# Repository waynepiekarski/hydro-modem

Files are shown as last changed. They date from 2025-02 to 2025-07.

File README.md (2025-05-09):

# HydroModem: Underwater Bell 103 modem implementation for low-power microcontrollers

Main project page: https://waynepiekarski.net/projects/hydro-modem.htm

HydroModem is a Bell 103 modem implementation to decode data from an always-on underwater hydrophone.
Designed for low-power microcontrollers such as AVR ATmega328P, it can listen underwater long-term
and implement the reliable trigger for an acoustic release in ocean research sensor prototypes.

This is an implementation of a Bell 103 modem decoder for Arduino devices with
low-power microcontrollers such as ATmega328P. It uses a simple Goertzel algorithm
to detect the power of two frequencies, compares them to determine mark-space bits,
and then decodes these into 8-bit characters. This method can handle background noise
and is used here to implement an acoustic underwater data transmit/receive mechanism.
Low-power devices can be permanently placed underwater, listening for a wakeup message,
and then take some kind of action like burn a nichrome wire for an acoustic release.
It is expected that the modem will run on its own ATmega328P since there is no time remaining,
and a co-processor like another ATmega328P will listen to the decoded characters and take action.
HydroModem is an easy-to-use component that can be used for building low-cost devices to support
research in the world's oceans.

This implementation supports a 2600 Hz sample rate on an ATmega328P at 16 MHz. Transmission
is with sine wave tones at 1070 Hz and 1270 Hz. The sample rate must be at least double the highest frequency
(Nyquist theorem) and during testing at low signal strength some sample rates were found to be more reliable than
others due to aliasing. This implementation supports up to 3300 Hz, but beyond that requires a higher clock
rate on the microcontroller, possibly using something like an ESP32S3. The input is read
in via the Arduino ADC, which needs to be able to capture samples at the frequency required.

The ATmega328P must be run at 16 MHz for 2600 Hz sample rate, requires at least 4.0V for this clock speed according to the datasheet,
and will draw 7 mA current or 0.028 W power. This is 1-2 orders of magnitude better than a Raspberry Pi running Linux, and capable
of running for weeks/months on a battery underwater.

# Sample audio

Sample audio generated by the modem tests, with spectrogram of the FSK frequencies in use, click for video:<br>
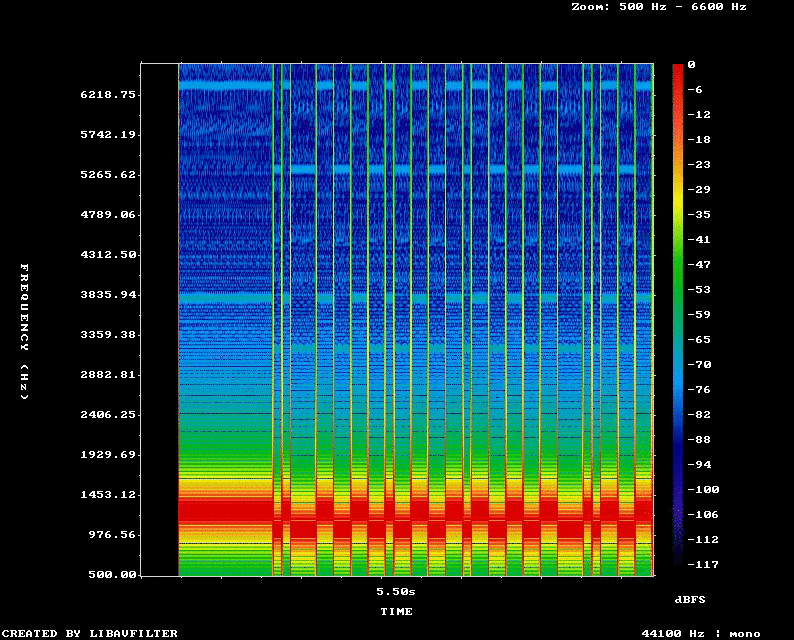
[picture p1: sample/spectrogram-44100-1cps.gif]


# Arduino Uno 16MHz on Linux command-line
The modemrx.ino project can be built on the command-line and also loaded into the Arduino IDE on any supported platform.
```
# Download arduino-cli (run once)
./download-arduino-tools

# Download arduino libraries (run once)
./download-arduino-libs

# Build and upload the modemrx project via USB serial
make -C modemrx upload

# Read characters decoded from the modemrx project
make -C modemrx read
```

# Listen and record audio on Linux via Arduino ADC
The recordwav.ino project allows you to listen to or record the audio at the ADC, making debugging with Linux tools easier.

```
# Download arduino-cli (run once)
./download-arduino-tools

# Download arduino libraries (run once)
./download-arduino-libs

# Build and upload the recordwav project via USB serial to record from the ADC
make -C recordwav upload

# Save audio to disk for offline testing
./recordwav/save_arduino_piezo.sh

# Listen to live audio on speakers
./recordwav/live_arduino_piezo.sh
```

# Linux testing of modem

The modem code also builds on Linux with the ability to encode to and decode from WAV files.
Automated regression tests are provided to ensure that different sample rates all work after changes are made.
Tests also verify that HydroModem's Bell 103 encoding is compatible with MiniModem <a href="http://www.whence.com/minimodem/">http://www.whence.com/minimodem/</a> on Linux.

```
# Download Debian/Ubuntu dependencies (run once)
./linux-test/apt-get-deps

# Build Linux binaries
make -C linux-test

# Generate WAV files using test strings
./linux-test/bell103_goertzel_wav_encoder

# Decode WAV files and recover test strings
./linux-test/bell103_goertzel_wav_decoder

# Run test suite that verifies encoding and decoding at various sample rates.
make -C linux-test test
```

# KiCAD v5 schematics and PCB layouts

These designs need to be tested in water and frequencies tuned for best performance.
Full project files are provided, including .kicad_pcb files for fabrication at <a href="https://oshpark.com">oshpark.com</a>.

## kicad/release-modem-mosfet-atmega328p-piezo/

Combination design implementing both the modem and the release mechanism.
5V ATmega328P running at 16 MHz.
Connects to a piezo-based microphone and includes protection diodes and an OPA1641 op-amp based on the
<a href="https://www.instructables.com/The-Gladys-Hydrophone/">Gladys Hydrophone by DJJules</a>.
Implements a P-channel MOSFET that can switch high-current 30 amps briefly to burn a nichrome release wire under water.
Provides on-board MCP1792 regulator for 5V from a >= 6.2V battery.
Arduino Uno-compatible AVRISP6 connector for programming.

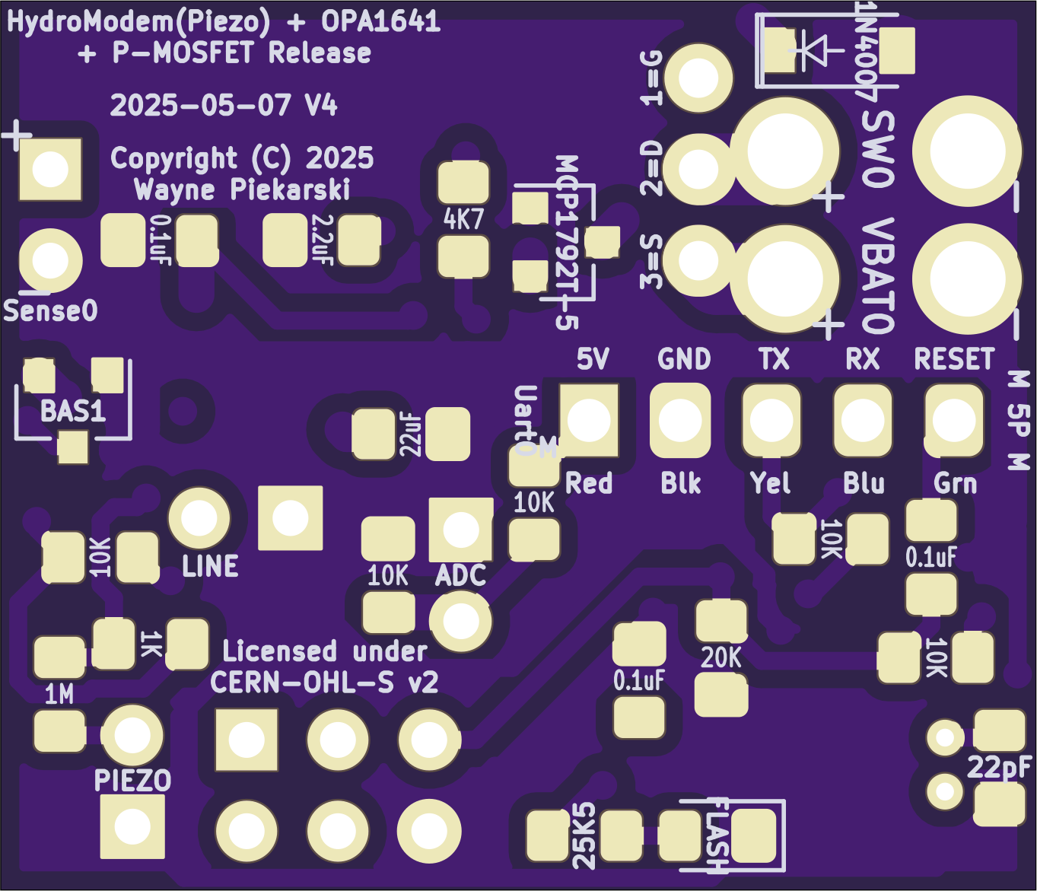
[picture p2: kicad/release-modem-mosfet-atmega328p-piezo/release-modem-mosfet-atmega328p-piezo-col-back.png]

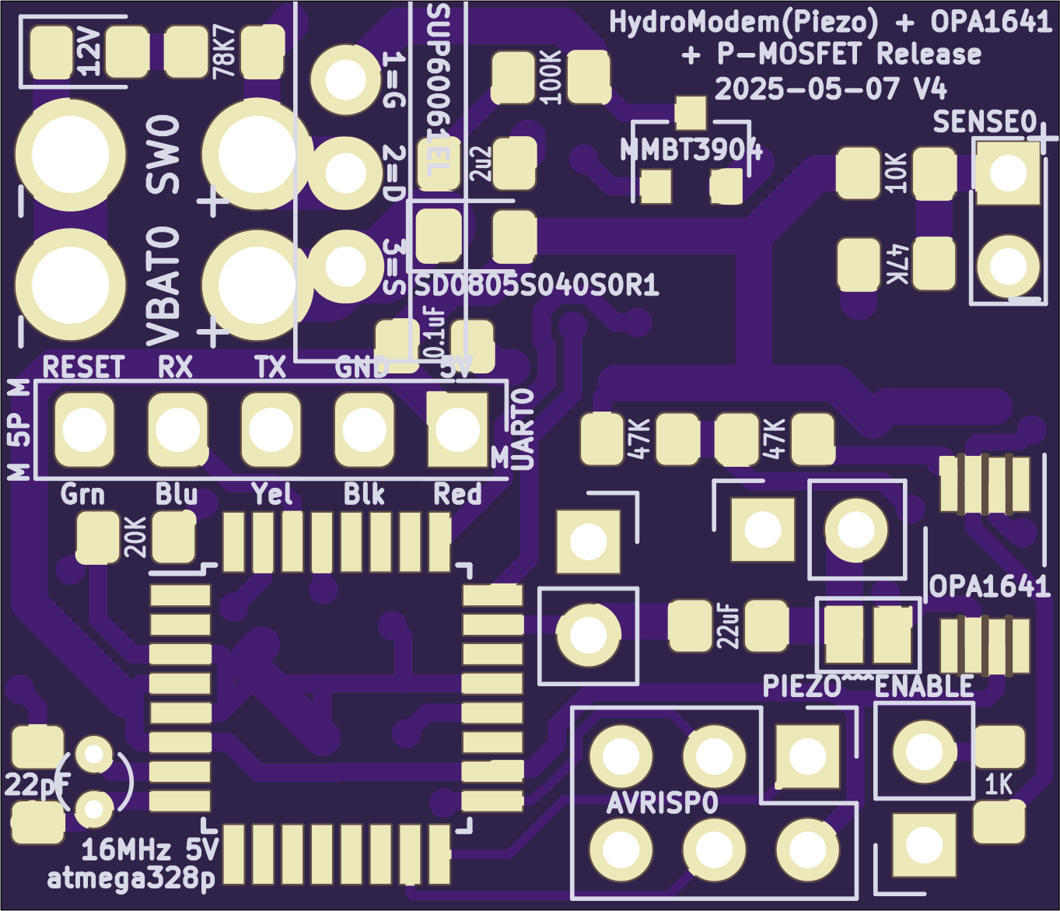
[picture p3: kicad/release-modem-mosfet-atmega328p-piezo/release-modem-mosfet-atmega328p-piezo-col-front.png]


<a href="kicad/release-modem-mosfet-atmega328p-piezo/release-modem-mosfet-atmega328p-piezo-schematic.pdf?raw=1">Schematics PDF</a>

<a href="kicad/release-modem-mosfet-atmega328p-piezo/design.kicad_pcb?raw=1">kicad_pcb</a>

## kicad/release-modem-atmega328p/

5V ATmega328P running at 16 MHz. Requires regulated 5V provided by the other board.
Connects to a piezo-based microphone and includes protection diodes and an OPA1641 op-amp based on the
<a href="https://www.instructables.com/The-Gladys-Hydrophone/">Gladys Hydrophone by DJJules</a>.
Only runs the HydroModem implementation, was used for early testing and separate from the release mechanism.
Arduino Uno-compatible AVRISP6 connector for programming.

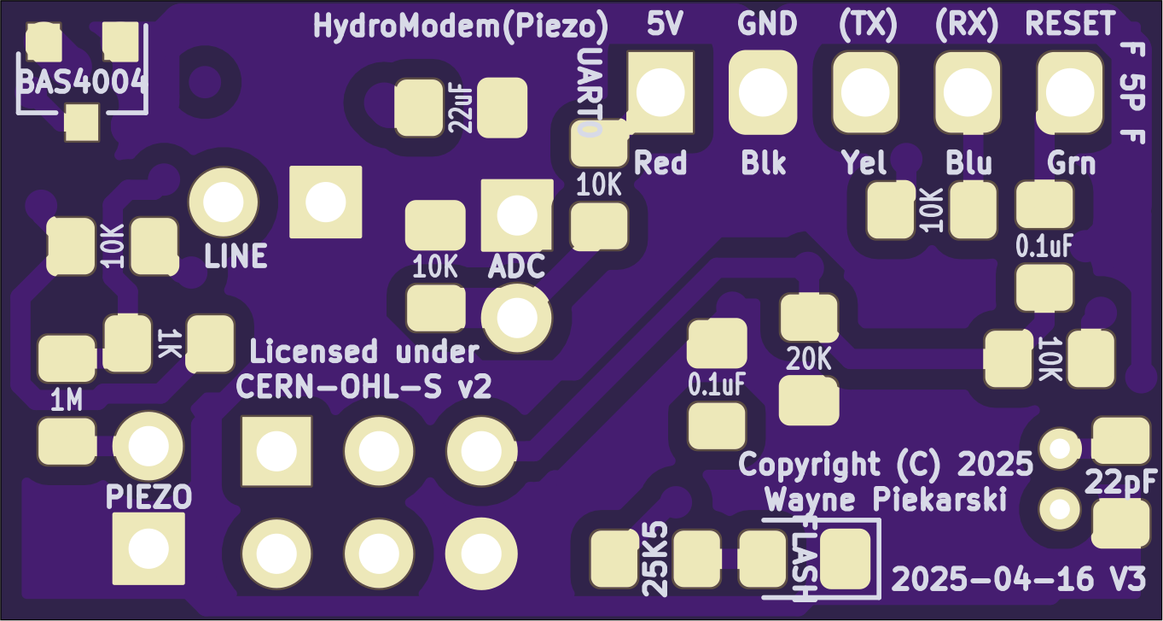
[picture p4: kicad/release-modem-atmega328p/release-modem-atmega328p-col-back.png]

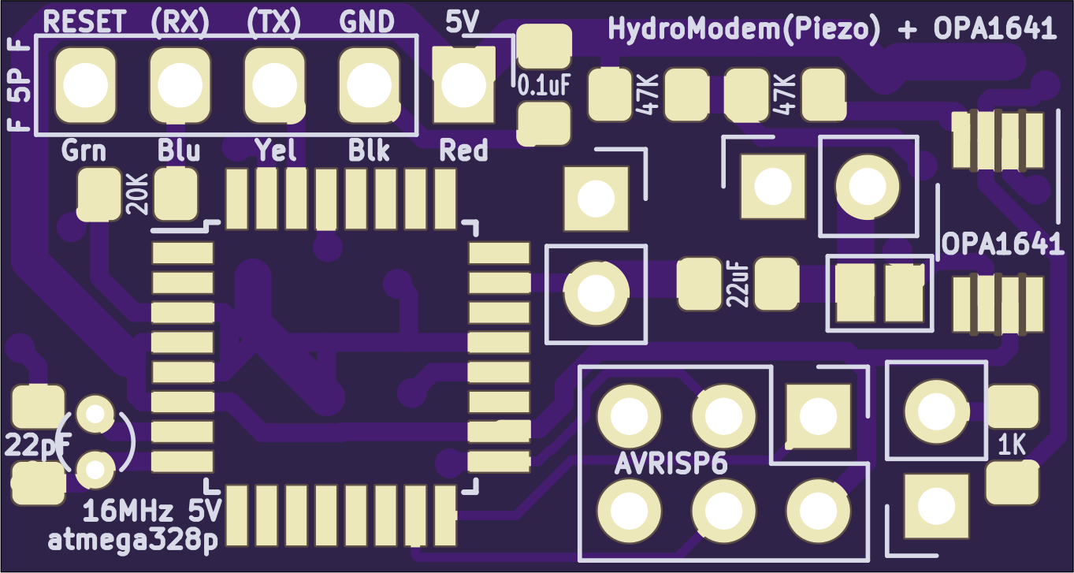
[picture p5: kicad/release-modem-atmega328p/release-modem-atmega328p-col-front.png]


<a href="kicad/release-modem-atmega328p/release-modem-atmega328p-schematic.pdf?raw=1">Schematics PDF</a>

<a href="kicad/release-modem-atmega328p/design.kicad_pcb?raw=1">kicad_pcb</a>

## kicad/release-modem-atmega328p-linein/

This is a simplified PCB design that does not provide any amplification for a piezo.
It connects any microphone that has been amplified to line-in voltages (+/- 1V) and passes this through to the ADC.
Only runs the HydroModem implementation and no release mechanism.

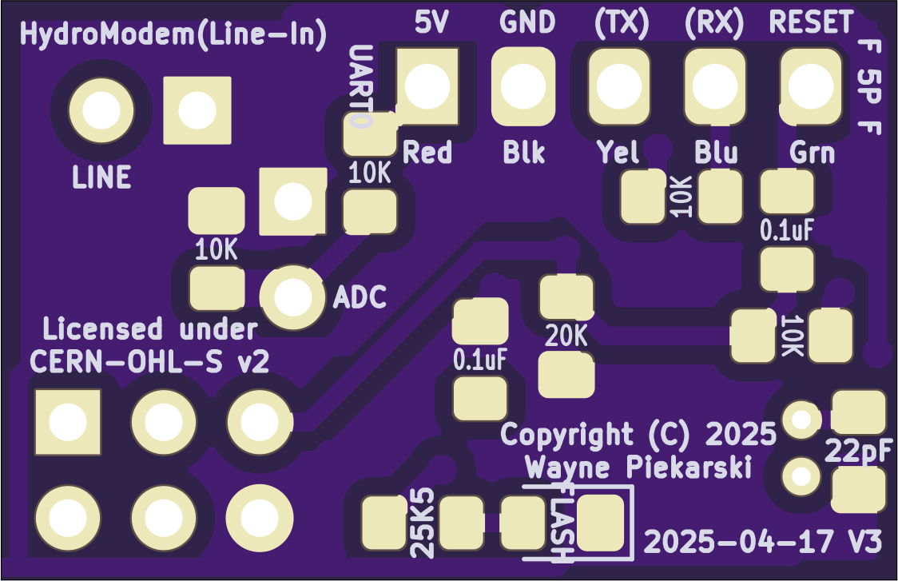
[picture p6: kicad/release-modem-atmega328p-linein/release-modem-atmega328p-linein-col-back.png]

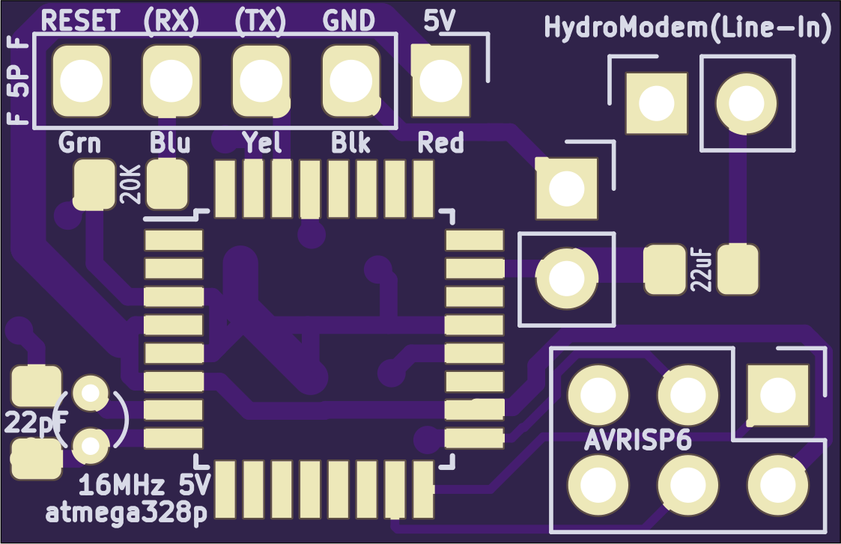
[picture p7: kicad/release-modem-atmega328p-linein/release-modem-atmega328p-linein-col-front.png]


<a href="kicad/release-modem-atmega328p-linein/release-modem-atmega328p-linein-schematic.pdf?raw=1">Schematics PDF</a>

<a href="kicad/release-modem-atmega328p-linein/design.kicad_pcb?raw=1">kicad_pcb</a>

## kicad/release-serial-i2c-atmega328p-switch/

3.3V ATmega328P running at 8 MHz. Implements a MOSFET that can switch high-current to burn a nichrome release wire.
Provides on-board MCP1792 regulators for 3.3V and 5V from a >= 6.2V battery. Arduino Uno-compatible AVRISP6 connector
for programming. Works with either of the standalone modem implementations above.

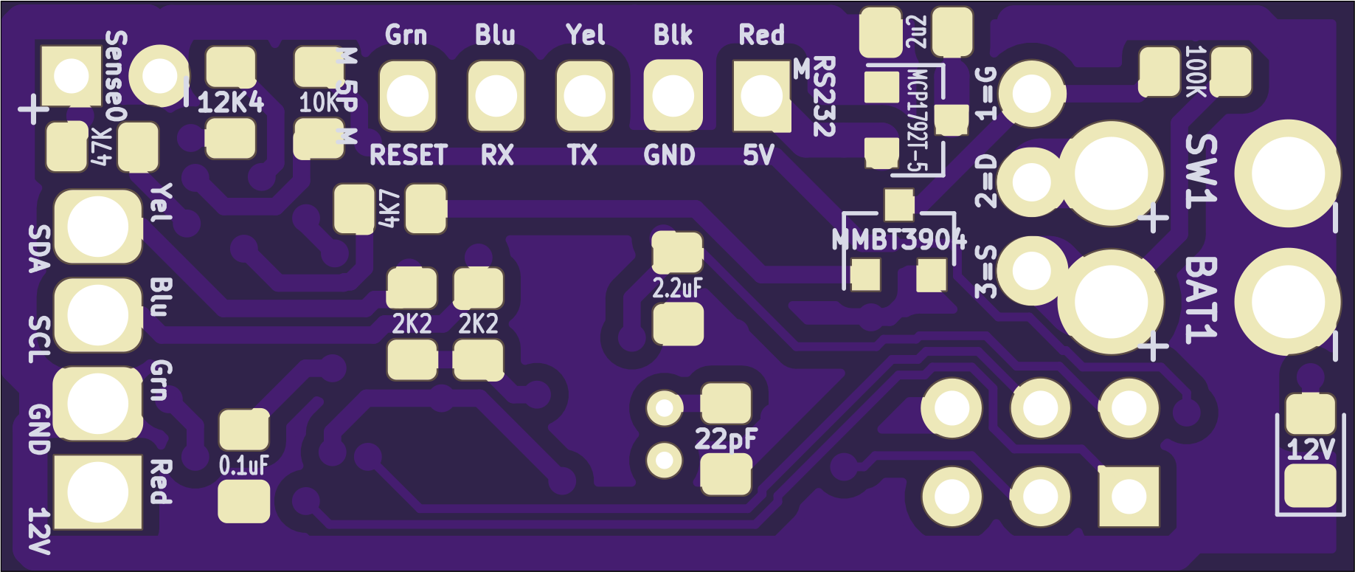
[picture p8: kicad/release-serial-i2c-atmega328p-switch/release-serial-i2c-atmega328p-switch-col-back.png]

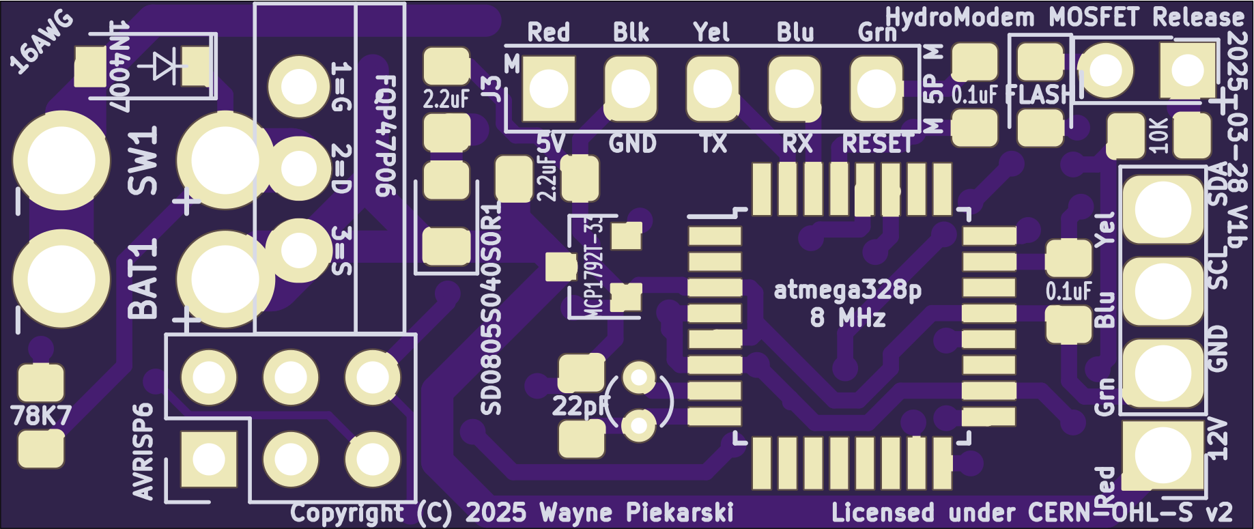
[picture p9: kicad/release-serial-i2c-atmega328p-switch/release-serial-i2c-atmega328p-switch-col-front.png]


<a href="kicad/release-serial-i2c-atmega328p-switch/release-serial-i2c-atmega328p-switch-schematic.pdf?raw=1">Schematics PDF</a>

<a href="kicad/release-serial-i2c-atmega328p-switch/design.kicad_pcb?raw=1">kicad_pcb</a>

# Source code GPLv3 license

HydroModem: Underwater Bell 103 modem implementation for low-power microcontrollers

Copyright (C) 2024-2025 Wayne Piekarski wayne@tinmith.net

https://waynepiekarski.net/projects/hydro-modem.htm

This program is free software: you can redistribute it and/or modify
it under the terms of the GNU General Public License as published by
the Free Software Foundation, either version 3 of the License, or
(at your option) any later version.

This program is distributed in the hope that it will be useful,
but WITHOUT ANY WARRANTY; without even the implied warranty of
MERCHANTABILITY or FITNESS FOR A PARTICULAR PURPOSE.  See the
GNU General Public License for more details.

You should have received a copy of the GNU General Public License
along with this program.  If not, see <http://www.gnu.org/licenses/>.

# KiCAD Schematics and PCB license CERN-OHL-S v2

This source describes Open Hardware and is licensed under the CERN-OHL-S v2.

You may redistribute and modify this source and make products using it under
the terms of the CERN-OHL-S v2 (https://ohwr.org/cern_ohl_s_v2.txt).

This source is distributed WITHOUT ANY EXPRESS OR IMPLIED WARRANTY,
INCLUDING OF MERCHANTABILITY, SATISFACTORY QUALITY AND FITNESS FOR A
PARTICULAR PURPOSE. Please see the CERN-OHL-S v2 for applicable conditions.

Source location: https://www.waynepiekarski.net/projects/hydro-modem.htm

As per CERN-OHL-S v2 section 4, should You produce hardware based on this
source, You must where practicable maintain the Source Location visible
on the external case of the device or other products you make using this
source.

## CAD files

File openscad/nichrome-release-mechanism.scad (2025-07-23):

// ------------------------------------------------------------------------------
//| HydroModem - Nichrome Release Mechanism                                      |
//| Copyright (C) Wayne Piekarski 2024-2025                                      |
//| https://www.waynepiekarski.net/projects/hydro-modem.htm                      |
//|                                                                              |
//| This source describes Open Hardware and is licensed under the CERN-OHL-S v2. |
//|                                                                              |
//| You may redistribute and modify this source and make products using it under |
//| the terms of the CERN-OHL-S v2 (https://ohwr.org/cern_ohl_s_v2.txt).         |
//|                                                                              |
//| This source is distributed WITHOUT ANY EXPRESS OR IMPLIED WARRANTY,          |
//| INCLUDING OF MERCHANTABILITY, SATISFACTORY QUALITY AND FITNESS FOR A         |
//| PARTICULAR PURPOSE. Please see the CERN-OHL-S v2 for applicable conditions.  |
//|                                                                              |
//| Source location: https://www.waynepiekarski.net/projects/hydro-modem.htm     |
//|                                                                              |
//| As per CERN-OHL-S v2 section 4, should You produce hardware based on this    |
//| source, You must where practicable maintain the Source Location visible      |
//| on the external case of the device or other products you make using this     |
//| source.                                                                      |
// ------------------------------------------------------------------------------

// Nichrome 80 wire, 32 AWG
// https://www.amazon.com/dp/B07CJ63YYT
// Nichrome 80-250' - 32 Gauge Wire - 250ft - 0.2mm - 0.008in - Made in USA - Master Wire Supply

mount_width = 10; // Using 10mm square washers with M3 holes to grab onto the nichrome wire
wire_length = 10; // Gap between washers for the nichrome wire to burn
bolt_length = 20;

base = 5;
height = 20;
length = 100;
width = mount_width*2 + wire_length;

arm_height = height - 5;
arm_offset = 1; // Need clearance or the arm is a tight fit to close
bolt_height = arm_height / 2;
arm_thickness = wire_length-2;

infinity = 100;

for (copy=[-1,1]) scale([copy,1,1]) {
    // Base with text
    if (copy > 0) {
        difference() {
            translate([0,0,-base/2])
                cube([width,length,base], center=true);
            translate([0,0,-1]) linear_extrude(2) {
                translate([-6,-2,0])
                    rotate([0,0,90])
                        text("Nichrome 80 32AWG", halign="center", valign="bottom", size=5);
                translate([0,+2,0])
                    rotate([0,0,90])
                        text("2025-06-11 v1", halign="center", valign="center", size=5);
                translate([+6,+2,0])
                    rotate([0,0,90])
                        text("HydroModem", halign="center", valign="top", size=5);
            }
        }
    }

    // Mount for rotating release arm bolt
    translate([width/2-mount_width,-length/2,0]) {
        difference() {
            cube([mount_width,2*arm_thickness,height]);
            translate([0,arm_thickness,bolt_height+arm_offset])
                rotate([0,90,0])
                    cylinder(d=6, $fn=4, h=infinity, center=true);
        }
    }

    // Mount for the electrical metric bolts
    translate([-mount_width/2+mount_width/2+wire_length/2,length/2-bolt_length,0]) {
        difference() {
            union() {
                inset = 3;
                // Inset slightly so the square washers do not rotate
                translate([0,inset,mount_width])
                    color("green") cube([mount_width,bolt_length-2*inset,mount_width]);
                color("orange") cube([mount_width,bolt_length,height-mount_width]);
            }
            translate([mount_width/2,0,height-mount_width/2+arm_offset])
                rotate([90,0,0])
                    cylinder(d=3, $fn=4, h=infinity, center=true);
        }
    }
}

// The hole didn't line up and needs an 0.5mm offset to align properly.
// Use *0 or *1 there are two places where it can be enabled.
bugfix = 0.5;

// Rotating rope holding arm with rounded ends
debug = false;
color("orange")
translate(debug ? [0,bugfix*1,arm_height/2+arm_offset] : [width,0,arm_thickness/2-base]) rotate(debug ? [0,0,0] : [0,90,0])
{
    difference() {
        hull() {
            translate([0,length/2-arm_height/2,0])
                rotate([0,90,0])
                    cylinder(d=arm_height, $fn=100, h=arm_thickness, center=true);
            translate([0,-(length/2-arm_height/2),0])
                rotate([0,90,0])
                    cylinder(d=arm_height, $fn=100, h=arm_thickness, center=true);
        }
        // Bolt hole for rotation
        translate([0,-(length/2-arm_height/2-bugfix*0),0])
            rotate([0,90,0])
                cylinder(d=6, $fn=100, h=infinity, center=true);
        
        // Area for rope to pass through, needs to be at an angle
        // so the rope slides out and doesn't get caught
        tweak_angle = 15;
        tweak_ofs = 2.8;
        rope_diameter = 10;

        translate([0,-length/2+arm_height*1.5,0-arm_height/2-tweak_ofs])
            rotate([0,90,0])
                rotate([0,0,tweak_angle])
                cylinder(d=rope_diameter*2, $fn=4, h=infinity, center=true);
    }
}

// Rotating rope holding arm with bolt end to not burn from nichrome
// TODO: Currently will be at an angle since the nichrome wire is higher than axis of rotation
debug2 = false;
color("cyan")
translate(debug2 ? [0,bugfix*1,arm_height/2+arm_offset] : [-width,0,arm_thickness/2-base]) rotate(debug2 ? [0,0,0] : [0,90,0])
{
    difference() {
        hull() {
            // -5mm to ensure the arm never interferes with the nichrome mount
            translate([0,length/2-arm_height/2-bolt_length-5,0])
                rotate([0,90,0])
                    cube([arm_height,arm_height,arm_thickness], center=true);
            translate([0,-(length/2-arm_height/2),0])
                rotate([0,90,0])
                    cylinder(d=arm_height, $fn=100, h=arm_thickness, center=true);
        }
        // Mounting hole to fasten M3 bolt to rest against the nichrome wire
        rotate([90,0,0])
            translate([0,0,-infinity/2])
                cylinder(d=3, $fn=4, h=infinity, center=true);
        
        // Bolt hole for rotation
        translate([0,-(length/2-arm_height/2-bugfix*0),0])
            rotate([0,90,0])
                cylinder(d=6, $fn=100, h=infinity, center=true);
        
        // Area for rope to pass through, needs to be at an angle
        // so the rope slides out and doesn't get caught
        tweak_angle = 15;
        tweak_ofs = 2.8;
        rope_diameter = 10;

        translate([0,-length/2+arm_height*1.5,0-arm_height/2-tweak_ofs])
            rotate([0,90,0])
                rotate([0,0,tweak_angle])
                cylinder(d=rope_diameter*2, $fn=4, h=infinity, center=true);
    }
}

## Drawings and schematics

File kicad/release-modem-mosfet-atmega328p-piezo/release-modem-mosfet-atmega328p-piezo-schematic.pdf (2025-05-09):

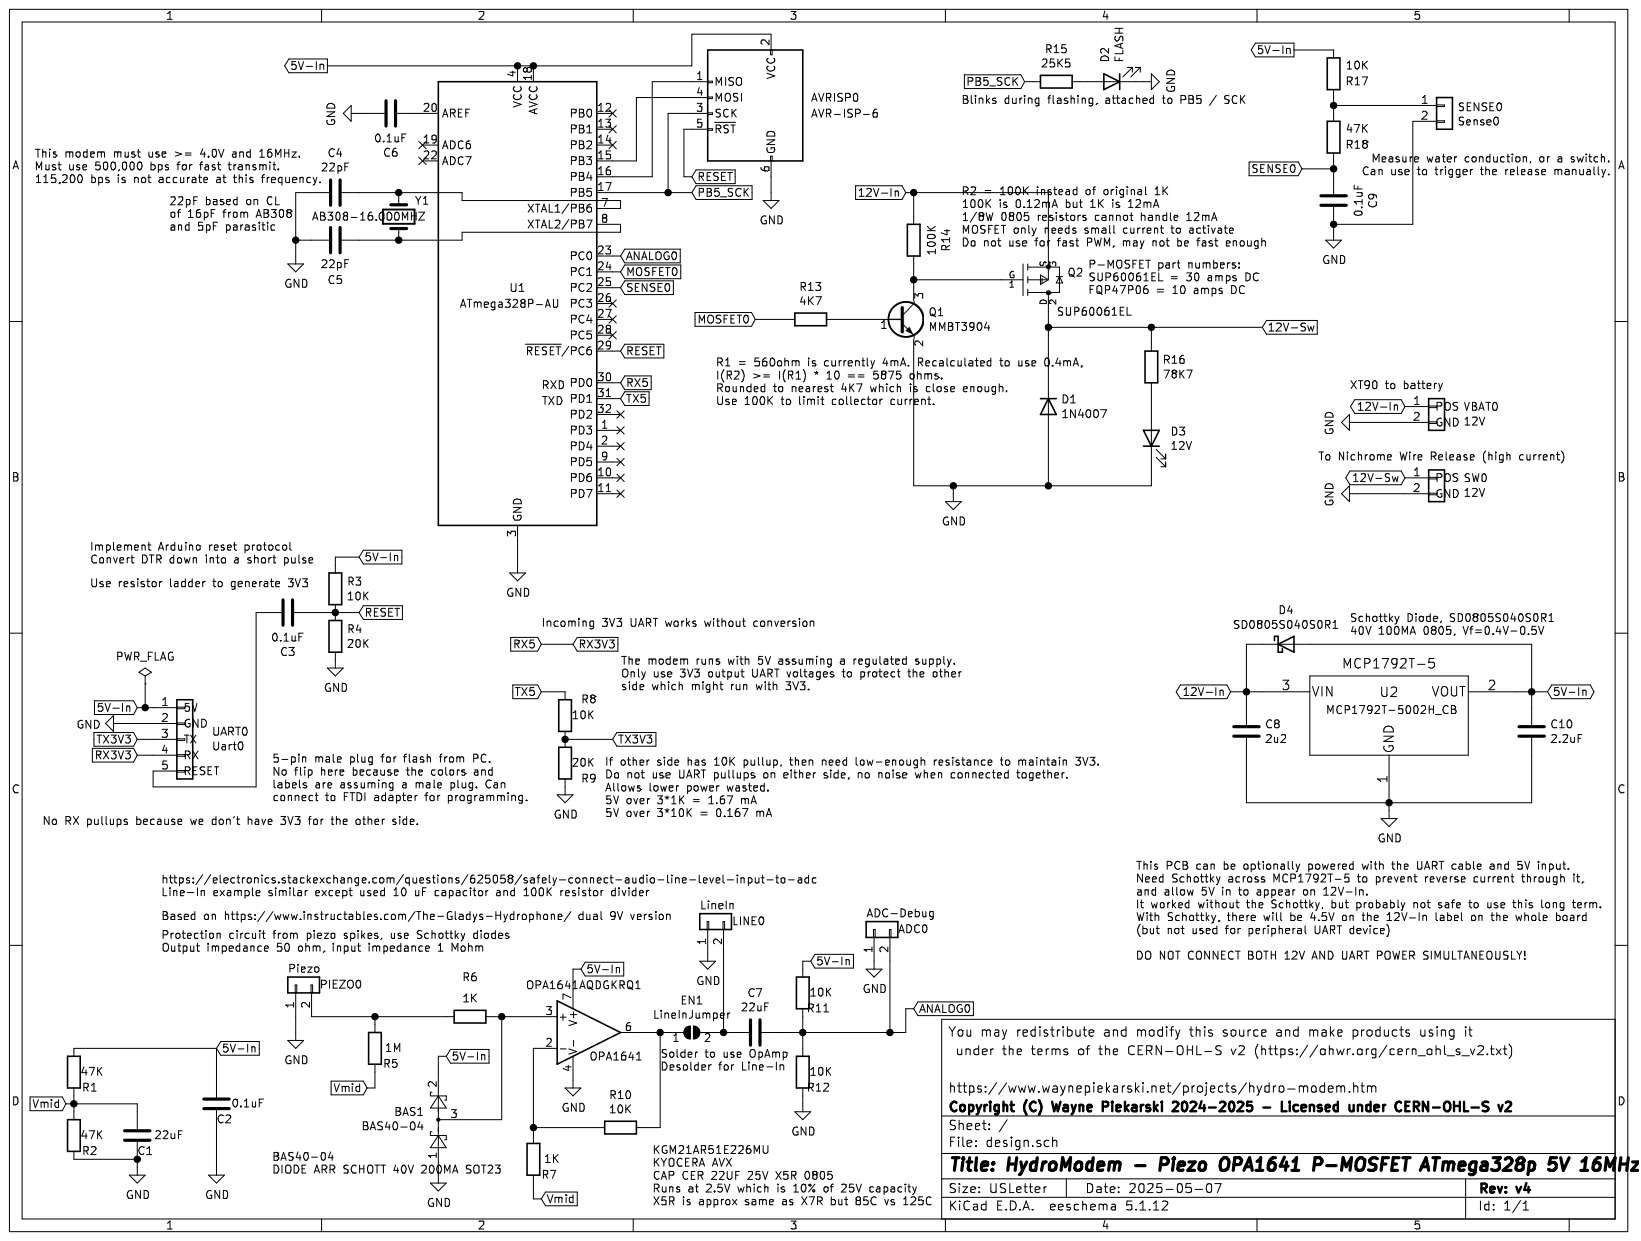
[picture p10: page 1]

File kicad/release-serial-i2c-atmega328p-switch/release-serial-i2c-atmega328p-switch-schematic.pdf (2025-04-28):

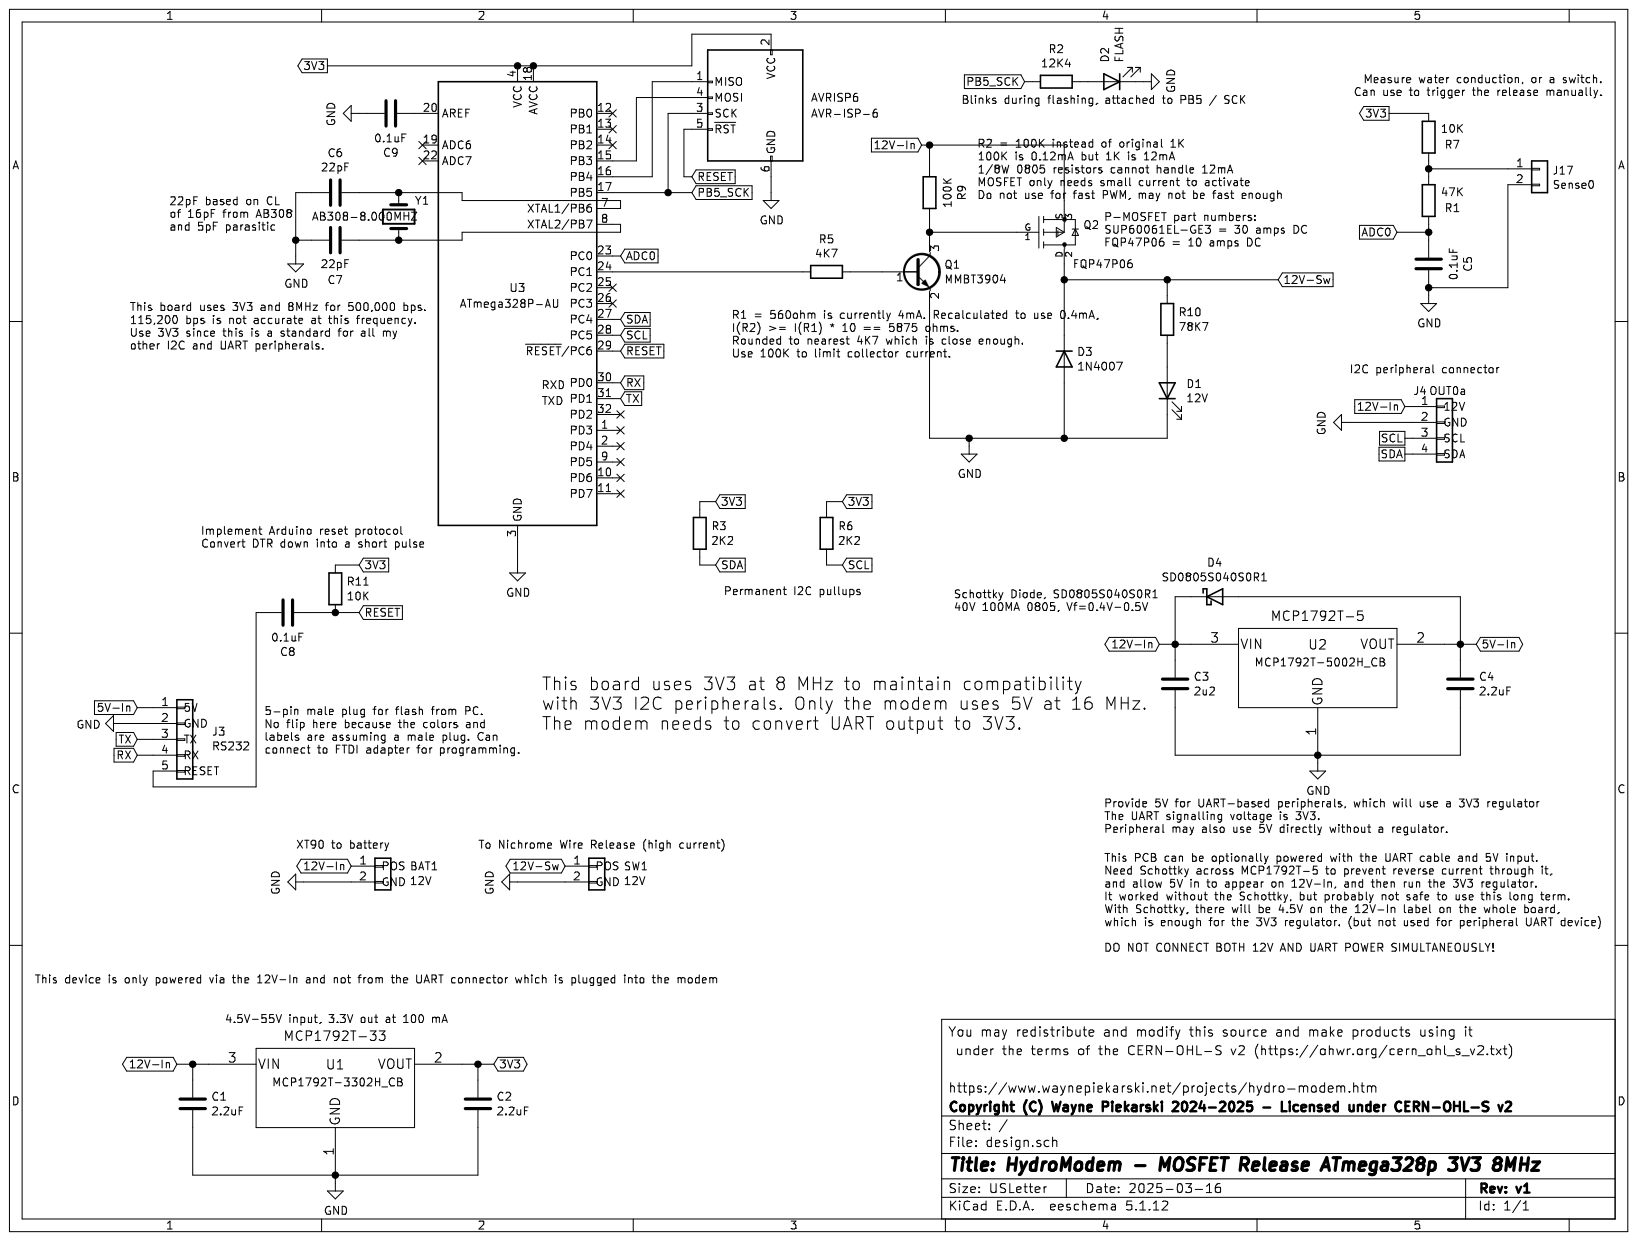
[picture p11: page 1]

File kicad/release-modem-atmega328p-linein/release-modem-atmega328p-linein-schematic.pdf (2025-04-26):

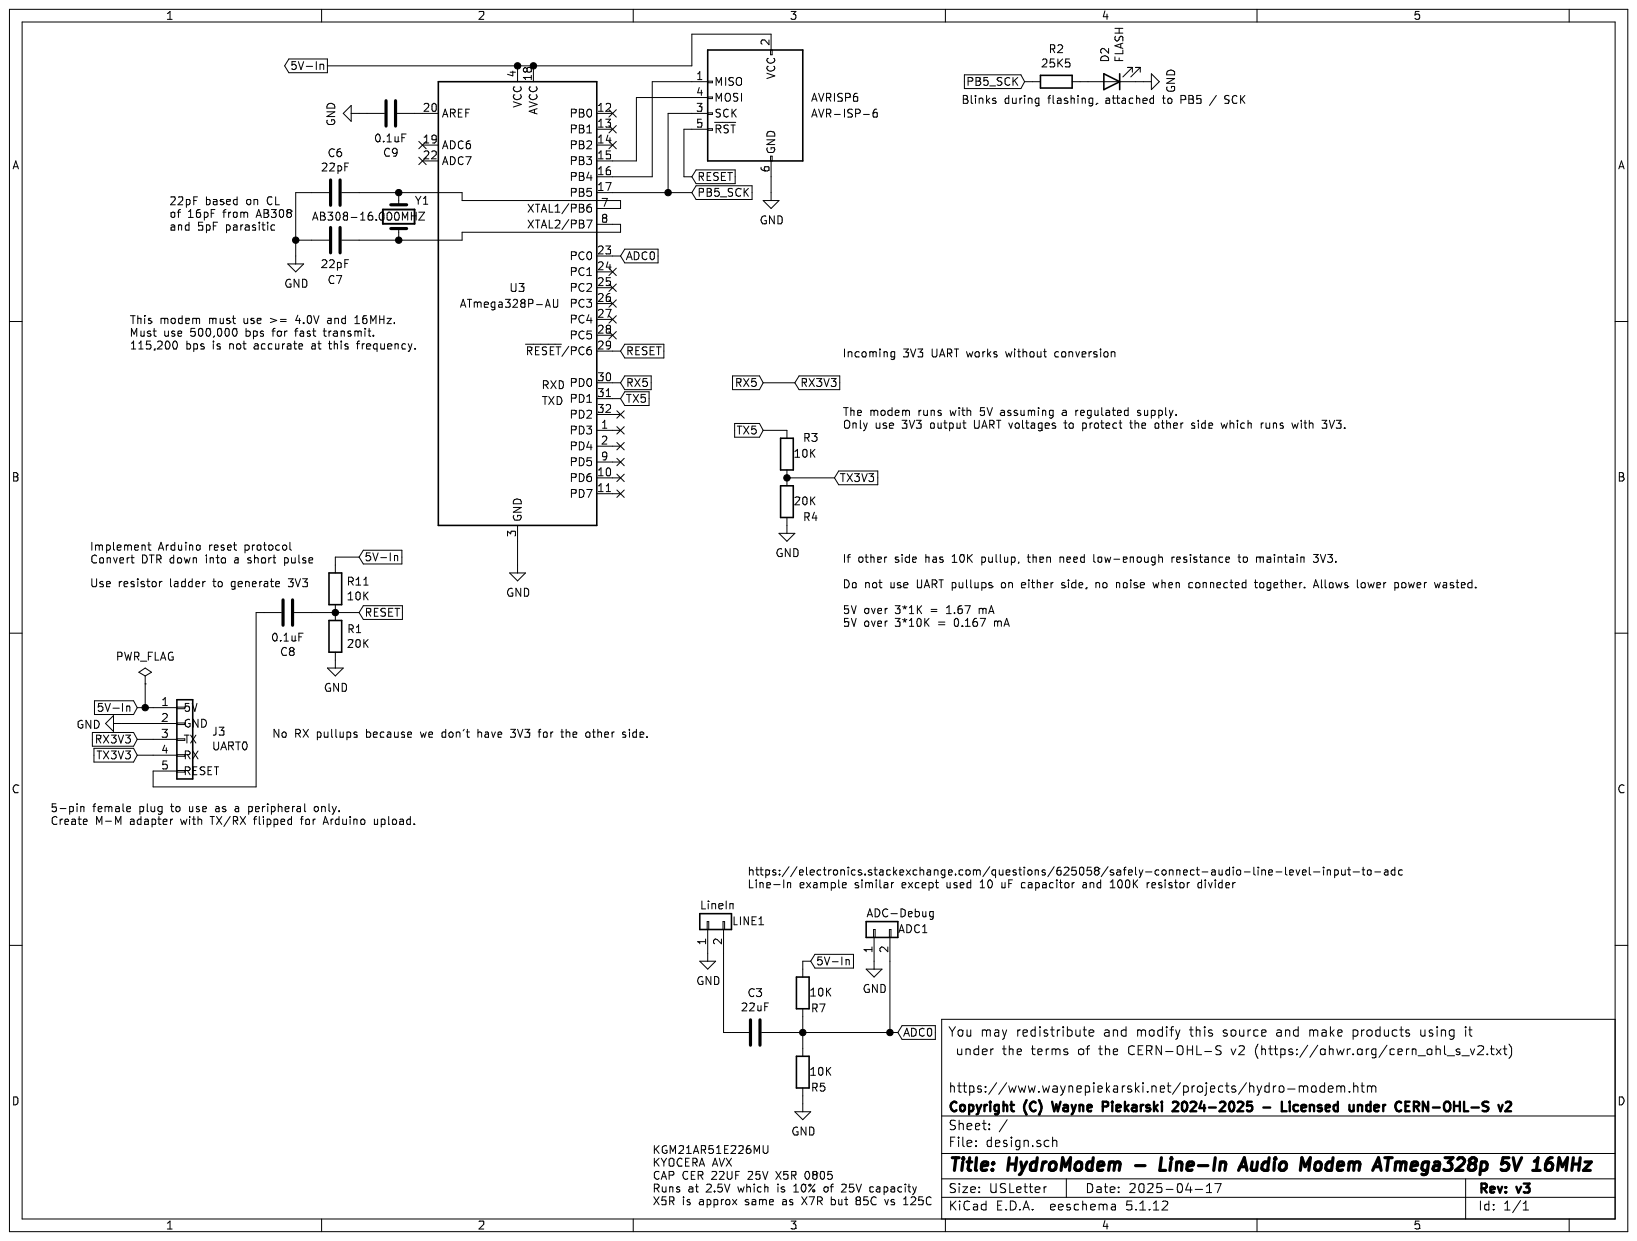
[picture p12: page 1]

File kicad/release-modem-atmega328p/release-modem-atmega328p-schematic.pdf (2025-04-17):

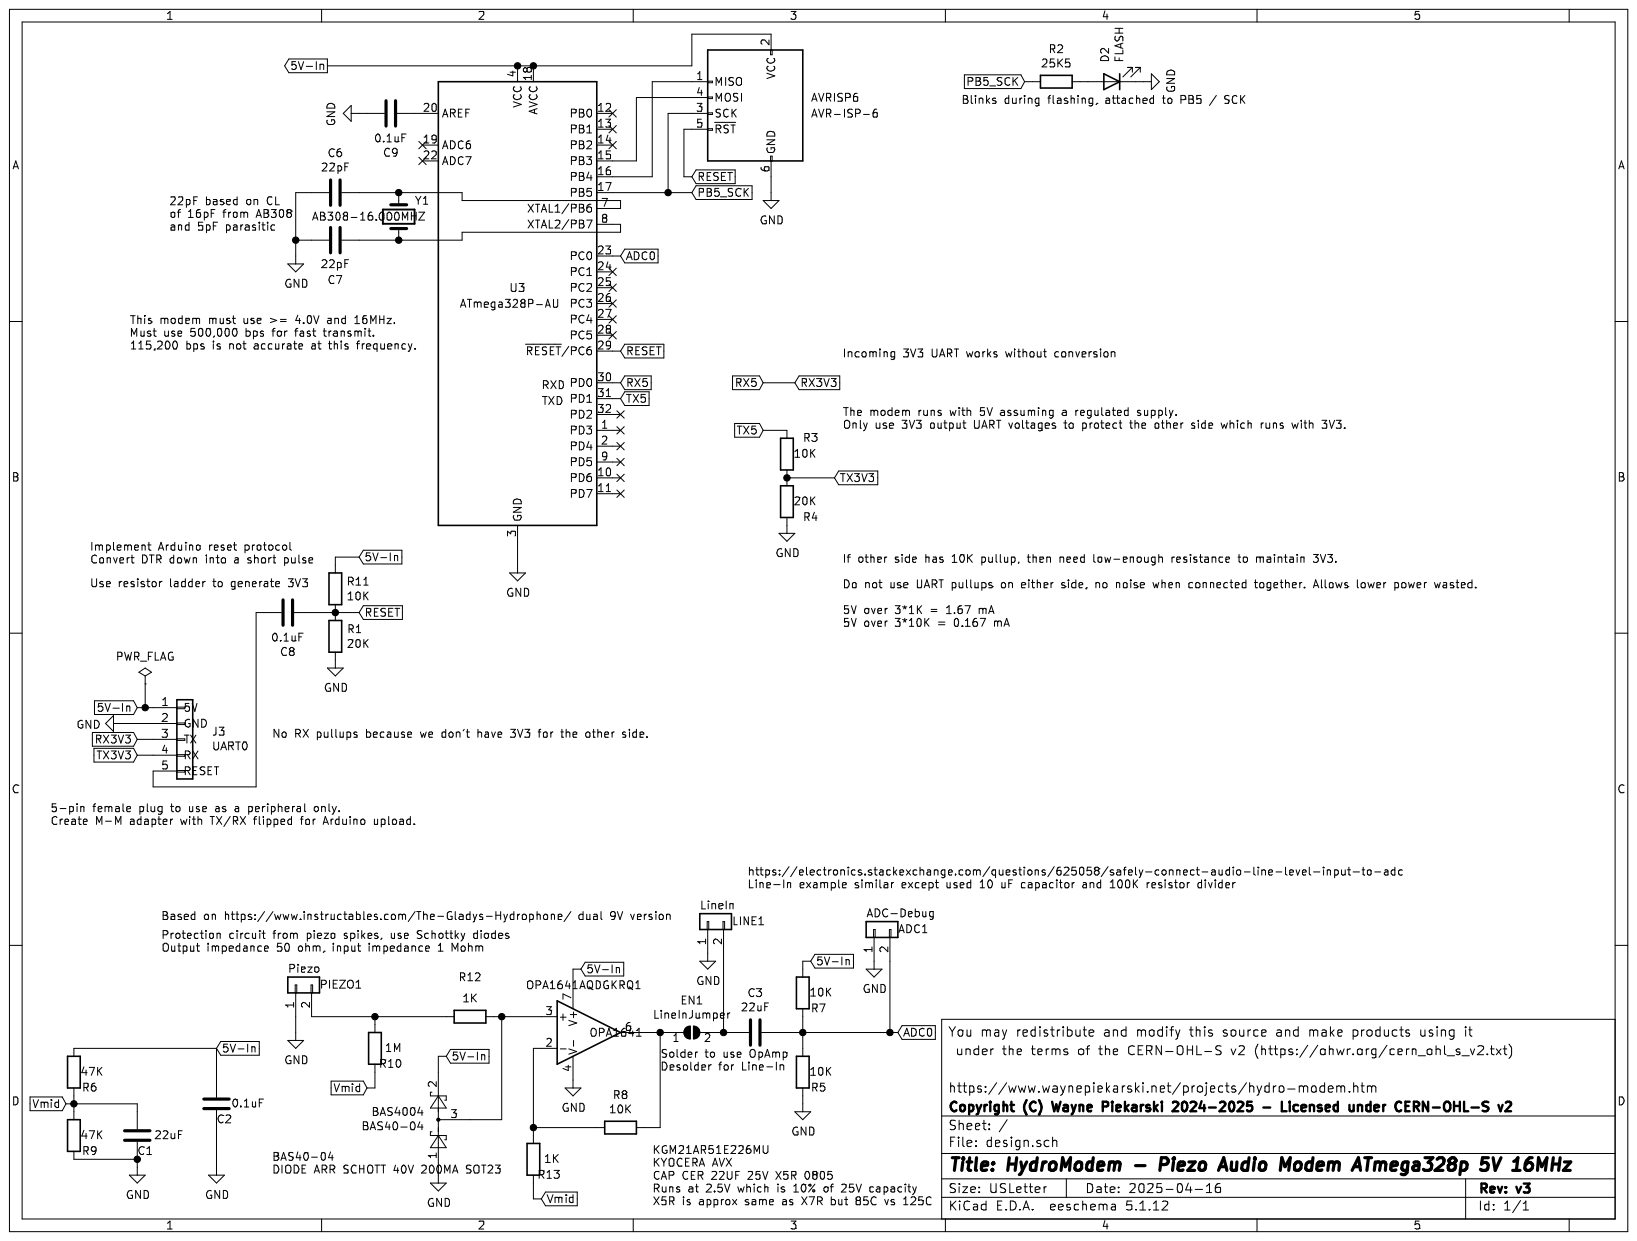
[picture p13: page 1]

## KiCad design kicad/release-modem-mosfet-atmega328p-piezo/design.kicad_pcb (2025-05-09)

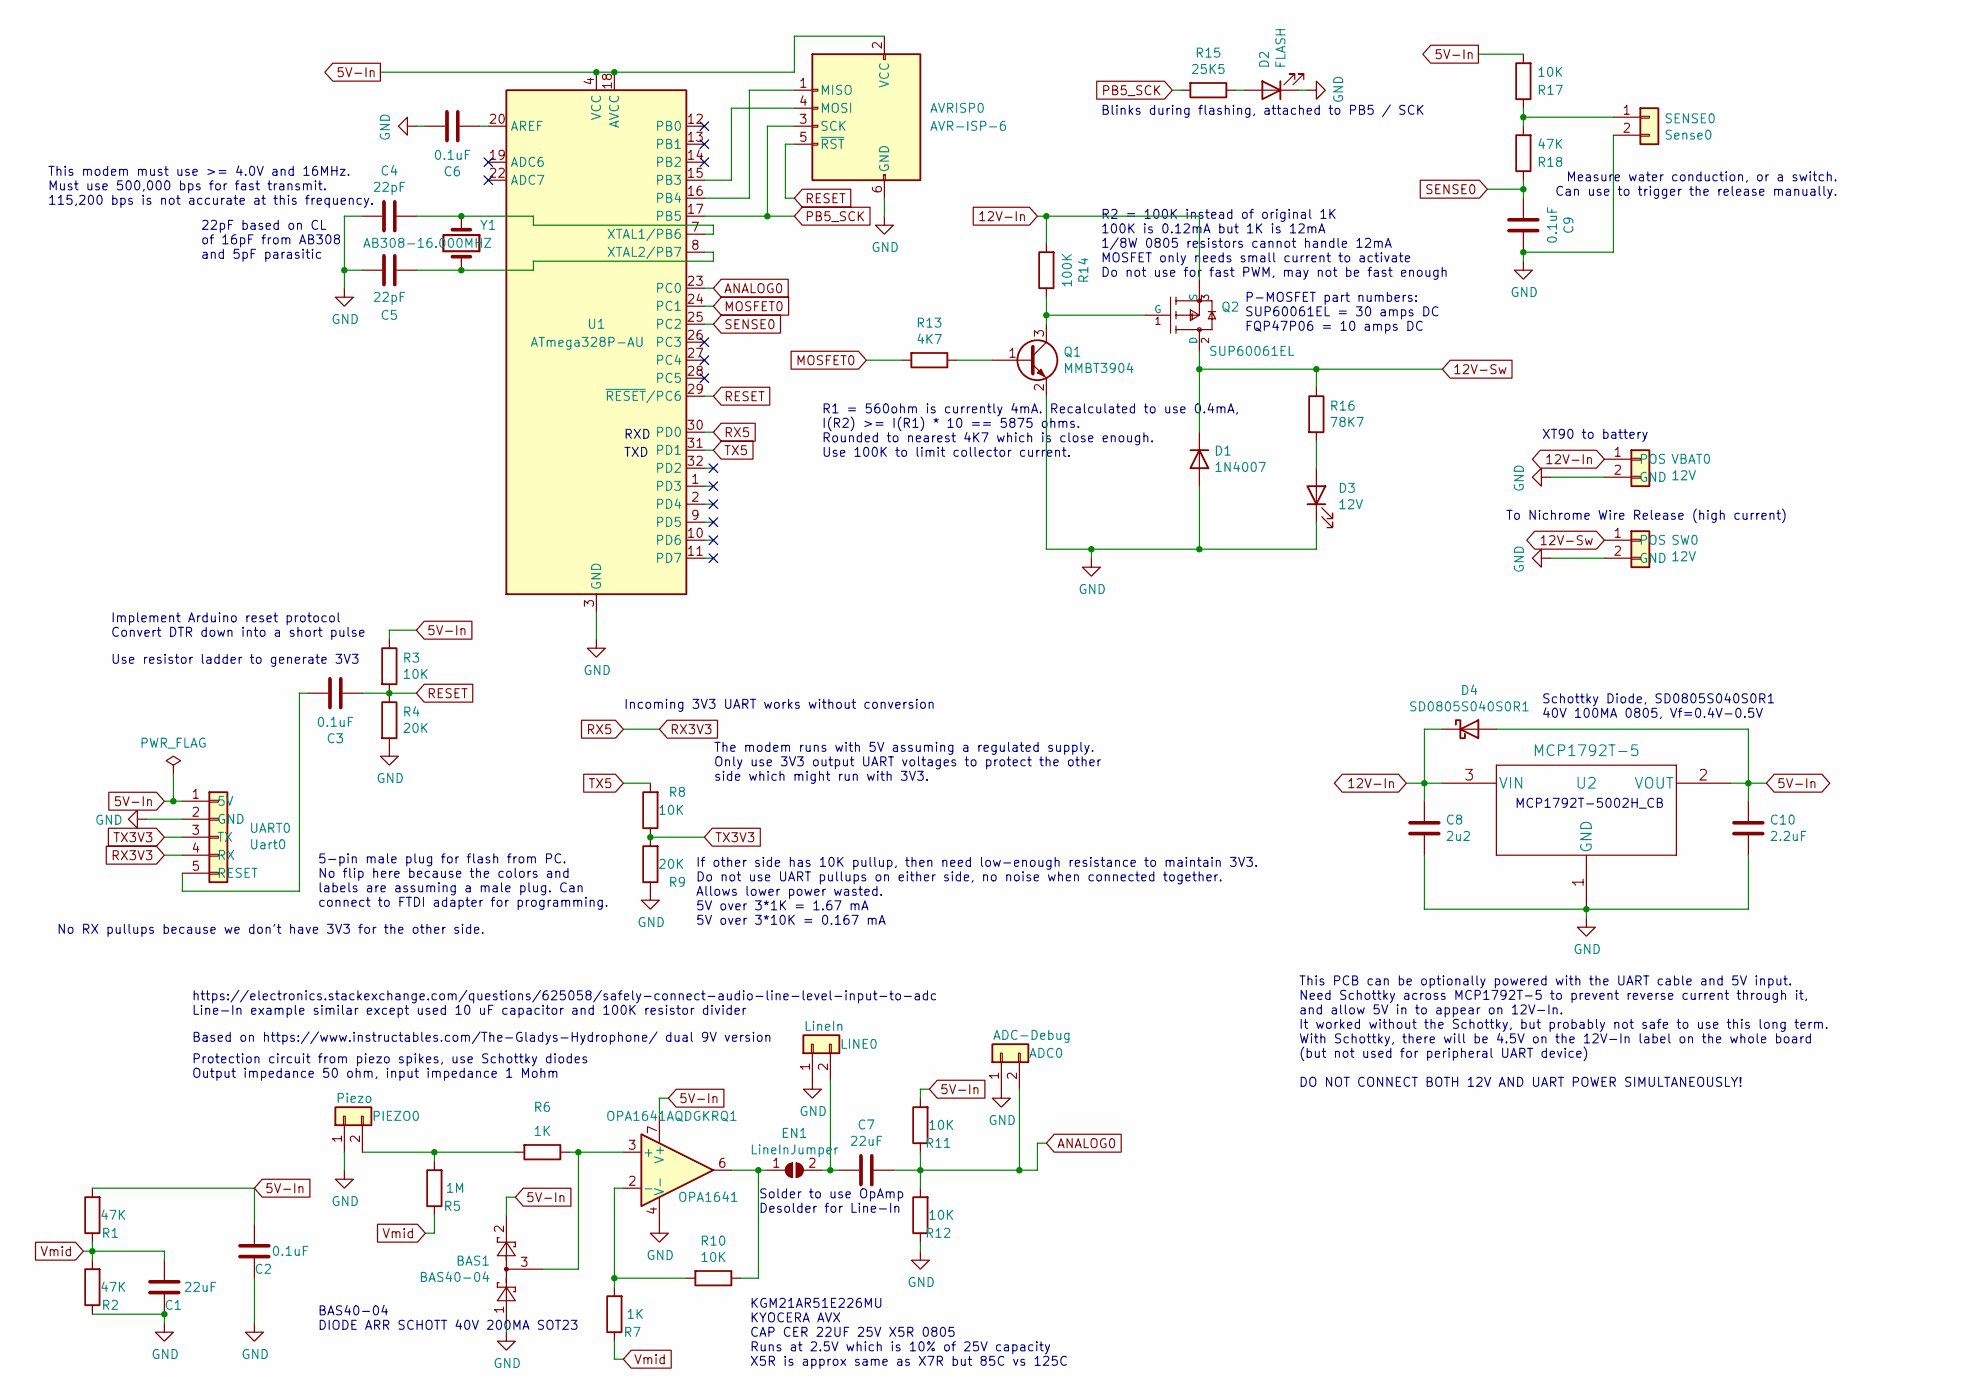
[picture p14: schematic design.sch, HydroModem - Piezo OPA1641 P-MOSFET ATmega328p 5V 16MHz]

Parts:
ADC0: ADC-Debug; WP_PinSocket_1x02_P2.54mm_Vertical
AVRISP0: AVR-ISP-6; PinHeader_2x03_P2.54mm_Vertical
BAS1: BAS40-04; SOT-23
C1, C7: 22uF; WP_C_0805_2012Metric_Pad1.15x1.40mm_HandSolder
C2, C3, C6, C9: 0.1uF; WP_C_0805_2012Metric_Pad1.15x1.40mm_HandSolder
C4, C5: 22pF; WP_C_0805_2012Metric_Pad1.15x1.40mm_HandSolder
C8: 2u2; WP_C_0805_2012Metric_Pad1.15x1.40mm_HandSolder; Part 08055C104KAT2A
C10: 2.2uF; WP_C_0805_2012Metric_Pad1.15x1.40mm_HandSolder; Part 08055C104KAT2A
D1: 1N4007; WP_D_SOD-123
D2: FLASH; WP_LED_0805_2012Metric_Pad1.15x1.40mm_HandSolder
D3: 12V; WP_LED_0805_2012Metric_Pad1.15x1.40mm_HandSolder
D4: SD0805S040S0R1; WP_LED_0805_2012Metric_Pad1.15x1.40mm_HandSolder
EN1: LineInJumper; SolderJumper-2_P1.3mm_Open_Pad1.0x1.5mm
LINE0: LineIn; WP_PinSocket_1x02_P2.54mm_Vertical
OPA1641: OPA1641AQDGKRQ1; VSSOP-8_3.0x3.0mm_P0.65mm
PIEZO0: Piezo; WP_PinSocket_1x02_P2.54mm_Vertical
Q1: MMBT3904; WP_SOT-23
Q2: SUP60061EL; WP_MOSFET_TO-220-3_Vertical; mouser part number 512-FQP47P06; digikey description MOSFET P-CH 60V 47A TO-220
R1, R2, R18: 47K; WP_R_0805_2012Metric_Pad1.15x1.40mm_HandSolder
R3, R8, R10, R11, R12, R17: 10K; WP_R_0805_2012Metric_Pad1.15x1.40mm_HandSolder
R4, R9: 20K; WP_R_0805_2012Metric_Pad1.15x1.40mm_HandSolder
R5: 1M; WP_R_0805_2012Metric_Pad1.15x1.40mm_HandSolder
R6, R7: 1K; WP_R_0805_2012Metric_Pad1.15x1.40mm_HandSolder
R13: 4K7; WP_R_0805_2012Metric_Pad1.15x1.40mm_HandSolder
R14: 100K; WP_R_0805_2012Metric_Pad1.15x1.40mm_HandSolder
R15: 25K5; WP_R_0805_2012Metric_Pad1.15x1.40mm_HandSolder
R16: 78K7; WP_R_0805_2012Metric_Pad1.15x1.40mm_HandSolder
SENSE0: Sense0; WP_Power_PinHeader_1x02_P2.54mm_Vertical
SW0: 12V; WP_TerminalBlock_16AWG_bornier-2_P5.08mm
U1: ATmega328P-AU; TQFP-32_7x7mm_P0.8mm
U2: MCP1792T-5; WP_SOT-23
UART0: Uart0; WP_Serial_5P_M
VBAT0: 12V; WP_TerminalBlock_16AWG_bornier-2_P5.08mm
Y1: AB308-16.000MHZ; Crystal_Round_D1.0mm_Vertical

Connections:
5V-In: AVRISP0.2 (VCC), BAS1.2, C2.2, C10.1, D4.2 (A), OPA1641.7 (V+), R1.2, R3.1, R11.2, R17.2, U1.4 (VCC), U1.6 (VCC), U1.18 (AVCC), U2.2 (VOUT), UART0.1 (5V)
12V-In: C8.1, D4.1 (K), Q2.3 (S), R14.2, U2.3 (VIN), VBAT0.1 (POS)
12V-Sw: D1.1 (K), Q2.2 (D), R16.1, SW0.1 (POS)
ANALOG0: ADC0.2, C7.1, R11.1, R12.2, U1.23 (PC0)
GND: ADC0.1, AVRISP0.6 (GND), BAS1.1, C1.1, C2.1, C4.2, C5.1, C6.1, C8.2, C9.1, C10.2, D1.2 (A), D2.1 (K), D3.1 (K), LINE0.1, OPA1641.4 (V-), PIEZO0.1, Q1.2 (E), R2.1, R4.2, R9.1, R12.1, SENSE0.2, SW0.2 (GND), U1.3 (GND), U1.5 (GND), U1.21 (GND), U2.1 (GND), UART0.2 (GND), VBAT0.2 (GND)
MOSFET0: R13.2, U1.24 (PC1)
unnamed: AVRISP0.1 (MISO), U1.16 (PB4)
unnamed: AVRISP0.4 (MOSI), U1.15 (PB3)
unnamed: BAS1.3, OPA1641.3 (+), R6.1
unnamed: C3.1, UART0.5 (RESET)
unnamed: C4.1, U1.7 (XTAL1/PB6), Y1.1
unnamed: C5.2, U1.8 (XTAL2/PB7), Y1.2
unnamed: C6.2, U1.20 (AREF)
unnamed: C7.2, EN1.2 (B), LINE0.2
unnamed: D2.2 (A), R15.1
unnamed: D3.2 (A), R16.2
unnamed: EN1.1 (A), OPA1641.6, R10.1
unnamed: OPA1641.2 (-), R7.2, R10.2
unnamed: PIEZO0.2, R5.2, R6.2
unnamed: Q1.1 (B), R13.1
unnamed: Q1.3 (C), Q2.1 (G), R14.1
unnamed: R17.1, R18.2, SENSE0.1
PB5_SCK: AVRISP0.3 (SCK), R15.2, U1.17 (PB5)
RESET: AVRISP0.5 (~RST), C3.2, R3.2, R4.1, U1.29 (~RESET~/PC6)
RX3V3: U1.30 (PD0), UART0.4 (RX)
SENSE0: C9.2, R18.1, U1.25 (PC2)
TX3V3: R8.1, R9.2, UART0.3 (TX)
TX5: R8.2, U1.31 (PD1)
Vmid: C1.2, R1.1, R2.2, R5.1, R7.1

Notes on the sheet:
RXD
TXD
Blinks during flashing, attached to PB5 / SCK
22pF based on CL of 16pF from AB308 and 5pF parasitic
This modem must use >= 4.0V and 16MHz. Must use 500,000 bps for fast transmit. 115,200 bps is not accurate at this frequency.
Implement Arduino reset protocol Convert DTR down into a short pulse
The modem runs with 5V assuming a regulated supply. Only use 3V3 output UART voltages to protect the other side which might run with 3V3.
If other side has 10K pullup, then need low-enough resistance to maintain 3V3. Do not use UART pullups on either side, no noise when connected together. Allows lower power wasted. 5V over 3*1K = 1.67 mA 5V over 3*10K = 0.167 mA
Incoming 3V3 UART works without conversion
No RX pullups because we don't have 3V3 for the other side.
Use resistor ladder to generate 3V3
Based on https://www.instructables.com/The-Gladys-Hydrophone/ dual 9V version
Protection circuit from piezo spikes, use Schottky diodes Output impedance 50 ohm, input impedance 1 Mohm
https://electronics.stackexchange.com/questions/625058/safely-connect-audio-line-level-input-to-adc Line-In example similar except used 10 uF capacitor and 100K resistor divider
KGM21AR51E226MU KYOCERA AVX CAP CER 22UF 25V X5R 0805 Runs at 2.5V which is 10% of 25V capacity X5R is approx same as X7R but 85C vs 125C
Solder to use OpAmp Desolder for Line-In
BAS40-04 DIODE ARR SCHOTT 40V 200MA SOT23
R2 = 100K instead of original 1K 100K is 0.12mA but 1K is 12mA 1/8W 0805 resistors cannot handle 12mA MOSFET only needs small current to activate Do not use for fast PWM, may not be fast enough
R1 = 560ohm is currently 4mA. Recalculated to use 0.4mA, I(R2) >= I(R1) * 10 == 5875 ohms. Rounded to nearest 4K7 which is close enough. Use 100K to limit collector current.
5-pin male plug for flash from PC. No flip here because the colors and labels are assuming a male plug. Can connect to FTDI adapter for programming.
Measure water conduction, or a switch. Can use to trigger the release manually.
XT90 to battery
MCP1792T-5002H_CB
Schottky Diode, SD0805S040S0R1 40V 100MA 0805, Vf=0.4V-0.5V
This PCB can be optionally powered with the UART cable and 5V input. Need Schottky across MCP1792T-5 to prevent reverse current through it, and allow 5V in to appear on 12V-In. It worked without the Schottky, but probably not safe to use this long term. With Schottky, there will be 4.5V on the 12V-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
To Nichrome Wire Release (high current)
P-MOSFET part numbers: SUP60061EL = 30 amps DC FQP47P06 = 10 amps DC

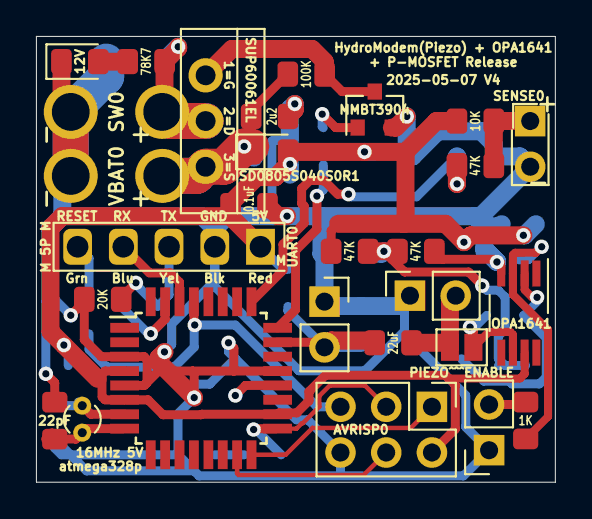
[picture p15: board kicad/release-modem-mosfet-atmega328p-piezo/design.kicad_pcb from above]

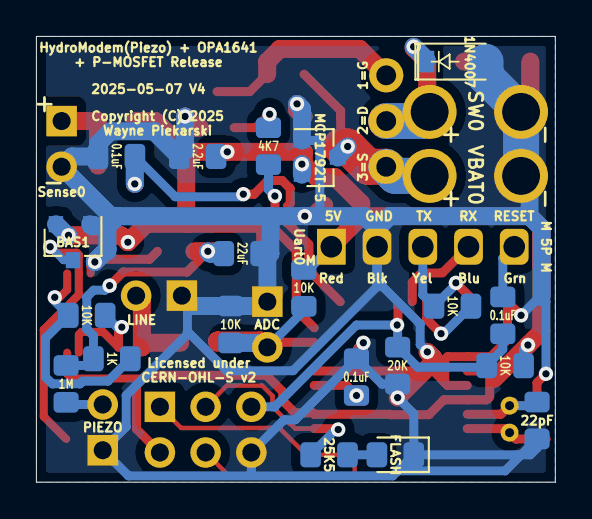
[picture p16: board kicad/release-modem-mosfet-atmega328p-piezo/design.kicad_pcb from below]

Board: 2 copper layers, 28.8 x 24.8 mm, 48 parts (20 on the bottom side), 29 nets.

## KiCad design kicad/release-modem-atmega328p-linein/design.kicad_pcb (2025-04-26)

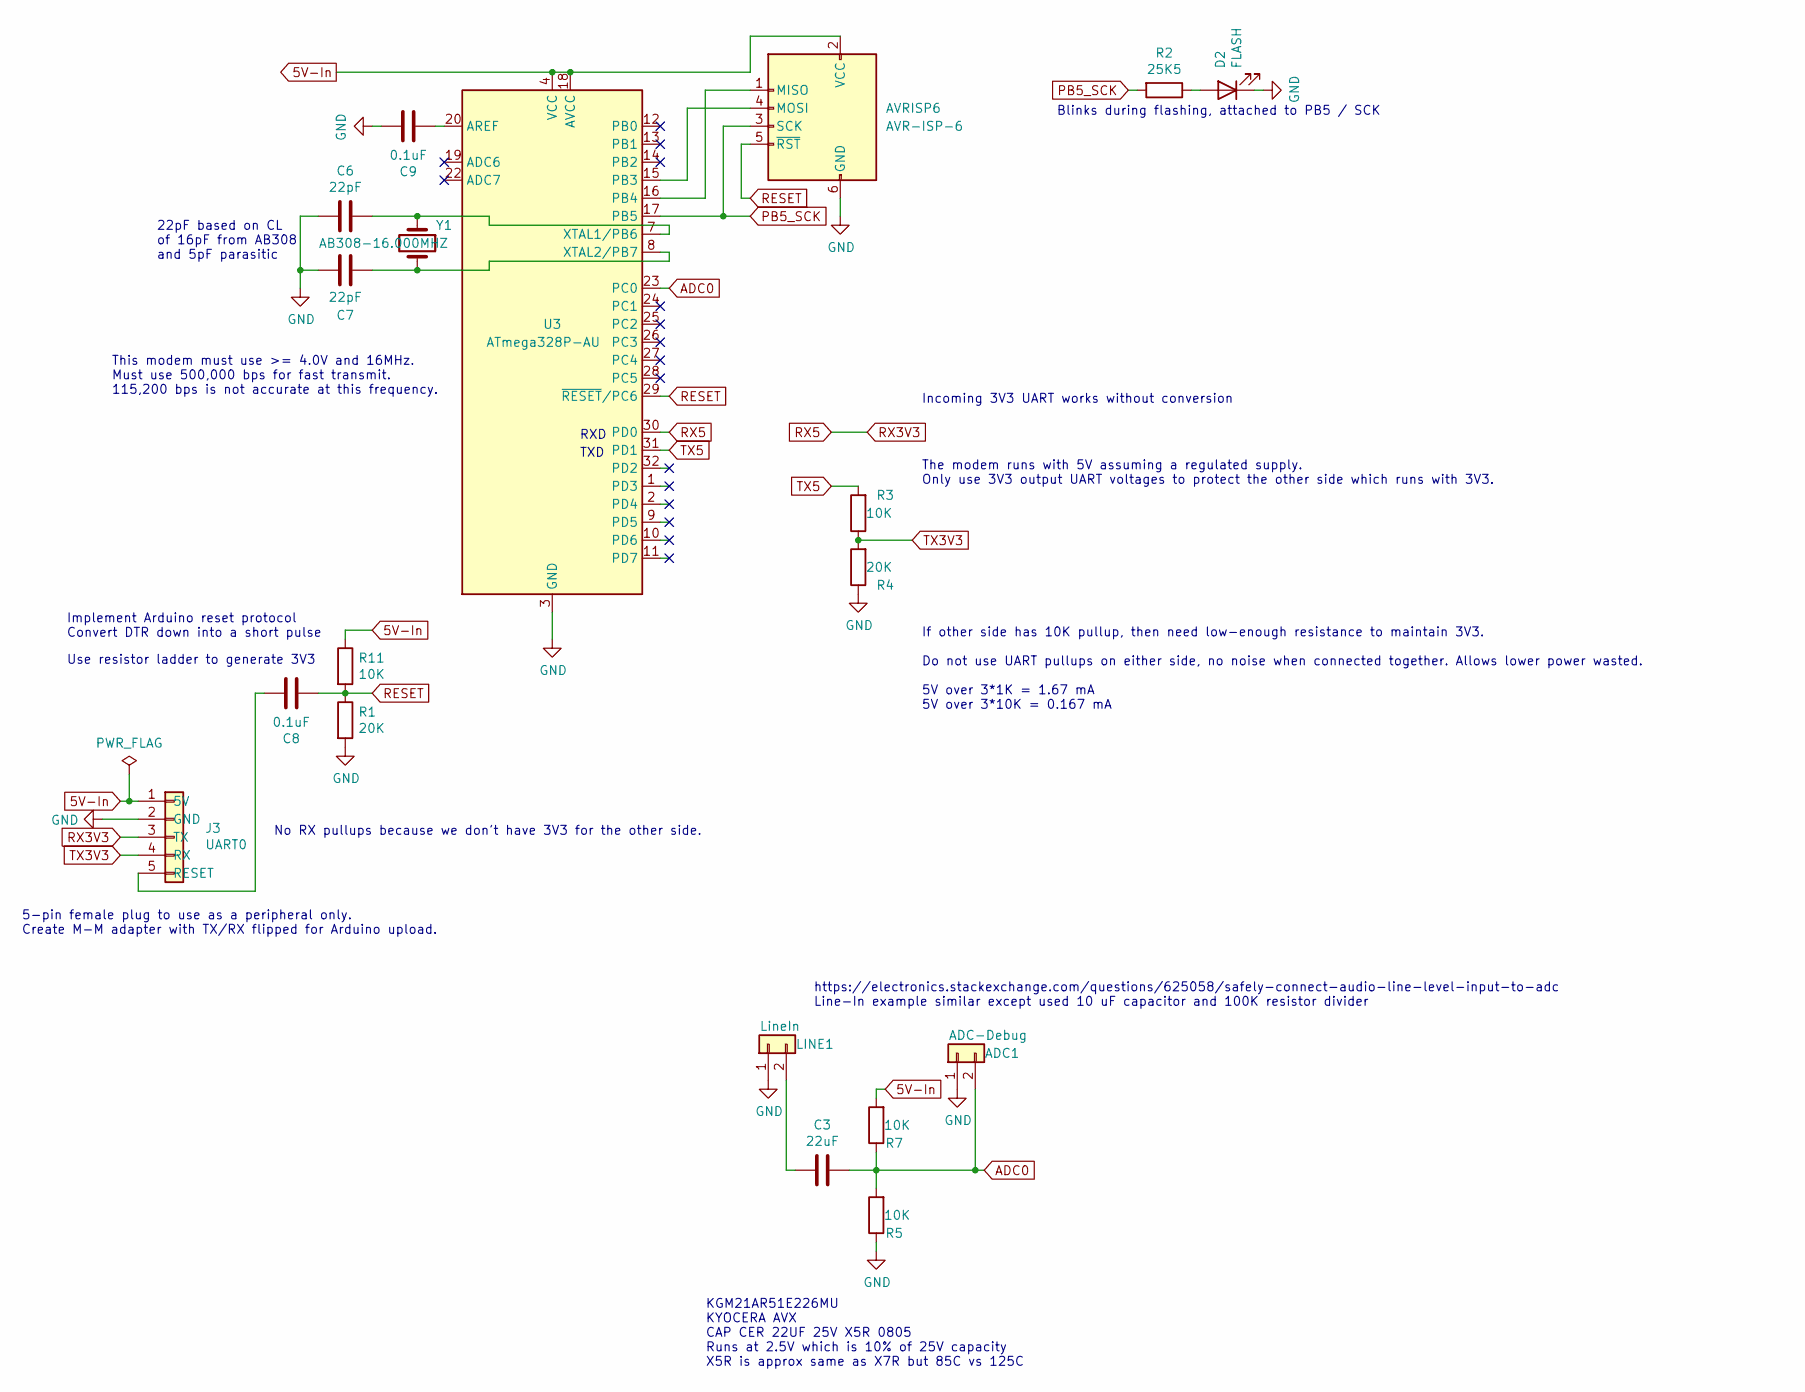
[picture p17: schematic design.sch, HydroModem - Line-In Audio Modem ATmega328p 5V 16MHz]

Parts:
ADC1: ADC-Debug; WP_PinSocket_1x02_P2.54mm_Vertical
AVRISP6: AVR-ISP-6; PinHeader_2x03_P2.54mm_Vertical
C3: 22uF; WP_C_0805_2012Metric_Pad1.15x1.40mm_HandSolder
C6, C7: 22pF; WP_C_0805_2012Metric_Pad1.15x1.40mm_HandSolder
C8, C9: 0.1uF; WP_C_0805_2012Metric_Pad1.15x1.40mm_HandSolder
D2: FLASH; WP_LED_0805_2012Metric_Pad1.15x1.40mm_HandSolder
J3: UART0; WP_Serial_5P_F
LINE1: LineIn; WP_PinSocket_1x02_P2.54mm_Vertical
R1, R4: 20K; WP_R_0805_2012Metric_Pad1.15x1.40mm_HandSolder
R2: 25K5; WP_R_0805_2012Metric_Pad1.15x1.40mm_HandSolder
R3, R5, R7, R11: 10K; WP_R_0805_2012Metric_Pad1.15x1.40mm_HandSolder
U3: ATmega328P-AU; TQFP-32_7x7mm_P0.8mm
Y1: AB308-16.000MHZ; Crystal_Round_D1.0mm_Vertical

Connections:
5V-In: AVRISP6.2 (VCC), J3.1 (5V), R7.2, R11.1, U3.4 (VCC), U3.6 (VCC), U3.18 (AVCC)
ADC0: ADC1.2, C3.1, R5.2, R7.1, U3.23 (PC0)
GND: ADC1.1, AVRISP6.6 (GND), C6.2, C7.1, C9.1, D2.1 (K), J3.2 (GND), LINE1.1, R1.2, R4.1, R5.1, U3.3 (GND), U3.5 (GND), U3.21 (GND)
unnamed: AVRISP6.1 (MISO), U3.16 (PB4)
unnamed: AVRISP6.4 (MOSI), U3.15 (PB3)
unnamed: C3.2, LINE1.2
unnamed: C6.1, U3.7 (XTAL1/PB6), Y1.1
unnamed: C7.2, U3.8 (XTAL2/PB7), Y1.2
unnamed: C8.1, J3.5 (RESET)
unnamed: C9.2, U3.20 (AREF)
unnamed: D2.2 (A), R2.1
PB5_SCK: AVRISP6.3 (SCK), R2.2, U3.17 (PB5)
RESET: AVRISP6.5 (~RST), C8.2, R1.1, R11.2, U3.29 (~RESET~/PC6)
RX3V3: J3.3 (TX), U3.30 (PD0)
TX3V3: J3.4 (RX), R3.1, R4.2
TX5: R3.2, U3.31 (PD1)

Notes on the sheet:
RXD
TXD
Blinks during flashing, attached to PB5 / SCK
22pF based on CL of 16pF from AB308 and 5pF parasitic
This modem must use >= 4.0V and 16MHz. Must use 500,000 bps for fast transmit. 115,200 bps is not accurate at this frequency.
Implement Arduino reset protocol Convert DTR down into a short pulse
The modem runs with 5V assuming a regulated supply. Only use 3V3 output UART voltages to protect the other side which runs with 3V3.
5-pin female plug to use as a peripheral only. Create M-M adapter with TX/RX flipped for Arduino upload.
If other side has 10K pullup, then need low-enough resistance to maintain 3V3. Do not use UART pullups on either side, no noise when connected together. Allows lower power wasted. 5V over 3*1K = 1.67 mA 5V over 3*10K = 0.167 mA
Incoming 3V3 UART works without conversion
No RX pullups because we don't have 3V3 for the other side.
Use resistor ladder to generate 3V3
https://electronics.stackexchange.com/questions/625058/safely-connect-audio-line-level-input-to-adc Line-In example similar except used 10 uF capacitor and 100K resistor divider
KGM21AR51E226MU KYOCERA AVX CAP CER 22UF 25V X5R 0805 Runs at 2.5V which is 10% of 25V capacity X5R is approx same as X7R but 85C vs 125C

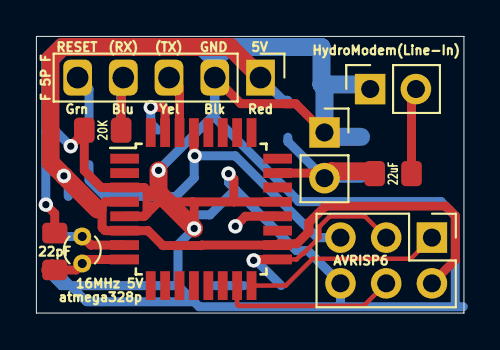
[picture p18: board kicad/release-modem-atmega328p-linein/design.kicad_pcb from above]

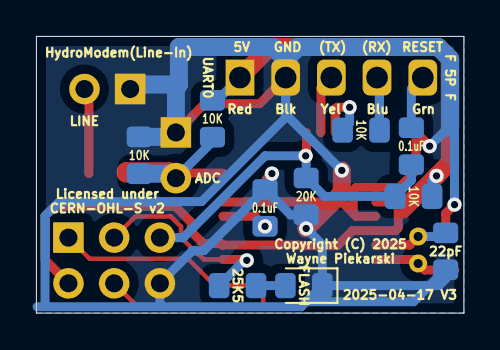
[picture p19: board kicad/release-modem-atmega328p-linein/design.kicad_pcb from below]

Board: 2 copper layers, 23.7 x 15.4 mm, 19 parts (10 on the bottom side), 16 nets.

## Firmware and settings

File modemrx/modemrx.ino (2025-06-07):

// ---------------------------------------------------------------------
//
// HydroModem
// Underwater Bell 103 modem implementation for low-power microcontrollers
//
// Copyright (C) 2024-2025 Wayne Piekarski
// wayne@tinmith.net https://waynepiekarski.net/projects/hydro-modem.htm
//
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
// ---------------------------------------------------------------------

#include <Arduino.h>

#ifdef __AVR__
// Verify this is running on an Arduino Uno, which is 16 MHz and not 8 Mhz
#if (F_CPU == 16000000)
#else
#error F_CPU is not configured for 16 MHz mode, this project is for Arduino Uno and should be run with: make arduino-uno-upload
#endif // F_CPU
#include <avr/interrupt.h>
#endif // __AVR__

#ifdef __AVR__
#define PIN_STATUS_LED 13 // PB5, SCK, standard Arduino Uno LED, physical 17)
static_assert(PIN_STATUS_LED == LED_BUILTIN);

// Attach piezo microphone to analog pin 0 to read audio from the ADC (pin 14 = A0 = PC0 = physical 23)
#define ANALOG_PIN A0
static_assert(ANALOG_PIN == 14);
// Attach oscilloscope to digital pin 7 to see pulse at the start and end of interrupt handler (digital pin 7 = PD7 = physical 11)
#define SCOPE_PIN  7
// Second oscilloscope pin which toggles if a sample has taken too long (digital pin 6 = PD6 = physical 10)
#define ERROR_PIN  6
// Manual trigger of the release mechanism, short pin to ground (pin 16 = A2 = PC2 = physical 25)
#define PIN_TRIGGER A2
static_assert(PIN_TRIGGER == 16);
// MOSFET release (pin 15 = A1 = PC1 = physical 24)
#define PIN_MOSFET 15
static_assert(PIN_TRIGGER != PIN_MOSFET);
static_assert(PIN_TRIGGER != ANALOG_PIN);
static_assert(PIN_MOSFET != ANALOG_PIN);
// Milliseconds the user must short the manual trigger wires before release
#define MANUAL_TRIGGER_MSEC 3000
// Milliseconds to activate the MOSFET for the release burn
#define WAKE_ACTIVE_MSEC 1000
#endif // __AVR__

#ifdef ARDUINO_ARCH_ESP32
#define ANALOG_PIN 0
#define SCOPE_PIN 7
#define ERROR_PIN 6
#endif // __ARDUINO_ARCH_ESP32

#ifndef MAKEFILE_BAUD
#define MAKEFILE_BAUD 500000
#endif // MAKEFILE_BAUD

#include "modem-const.h"

char wake_word[] = "WAKE";

// Only enable one of these at a time, cannot measure time in interrupt handlers
// #define BENCHMARKING

// Interrupt handler or loop timing can be used
// #define INTERRUPT_HANDLER

#ifdef BENCHMARKING
#ifdef INTERRUPT_HANDLER
#error Cannot perform benchmarking within an interrupt handler
#endif
#endif


#ifdef __AVR__
// On atmega328p, double and float are the same, so there is no performance
// improvement from float compared to double.
static_assert(sizeof(double) == sizeof(float));
#endif // __AVR__

inline void emit_bit(bool) {
    // Only used on Linux for debugging
}

char *wake_ptr = wake_word;

void trigger_mosfet (void) {
    Serial.println("MOSFET ON-WAIT");
    digitalWrite(PIN_MOSFET, HIGH);
    delay(WAKE_ACTIVE_MSEC);
    Serial.println("MOSFET OFF");
    digitalWrite(PIN_MOSFET, LOW);
}

void emit_goertzel(char out) {
    (void)(out); // Tell compiler it is ok to be unused

    // Must be a cheap operation since it is called from process_goertzel in the timing loop
    // Disable this when we measure performance on the oscilloscope
    // At  115200 baud, one bit = 8.7 usec, 1 byte = ~87 usec (4 KHz = 250 usec)
    // At  500000 baud, one bit = 2.0 usec, 1 byte = ~20 usec
    // At 1000000 baud, one bit = 1.0 usec, 1 byte = ~10 usec

    // Filter out garbage decoded values to not corrupt the terminal
    if ((out >= ' ') && (out <= '~')) {
        Serial.print(out);
    } else {
        Serial.print('?');
    }

    // Implement wake word detector
    if (out == *wake_ptr) {
        // Match, go to the next letter
        wake_ptr++;

        // Enable the LED for a match
        digitalWrite(LED_BUILTIN, true);
    } else {
        // No match, so reset to the start
        wake_ptr = wake_word;

        // Disable the LED since no match
        digitalWrite(LED_BUILTIN, false);
    }
    // Does the wake word match yet?
    if (*wake_ptr == '\0') {
        Serial.println ("");
        Serial.println ("Wake word detected");
        trigger_mosfet();
        wake_ptr = wake_word;
    }

#ifdef DEBUG_SPARE_CPU
    // Invert the LED to show a char was processed
    // Done in a loop to burn spare CPU time and look to see how much remains
    // Do this an odd number of times otherwise you won't observe the LED change
    // Currently this can be set to 8 without triggering a timeout
    for (uint8_t i = 0; i < 7; i++) {
        bool value = digitalRead(LED_BUILTIN);
        digitalWrite(LED_BUILTIN, !value);
    }
#endif // DEBUG_SPARE_CPU

    // Implement the manual release detection
    
    // Wires open is 1, shorted/conducting is 0
    bool trigger_current = !digitalRead(PIN_TRIGGER);
    static unsigned long last_trigger_time = 0;
    static unsigned long last_trigger_current = 0;
    static bool trigger_state = false;
    // Initialize static variables
    if (last_trigger_time == 0) {
        last_trigger_time = millis();
        last_trigger_current = trigger_current;
        trigger_state = false;
    }

    if (last_trigger_current != trigger_current) {
        // Trigger changed state, so restart the clock
        last_trigger_time = millis();
        last_trigger_current = trigger_current;
        if (trigger_current) {
            // Serial.println("Trigger pin change to pressed");
        } else {
            // Serial.println("Trigger pin change to released");
        }
    } else {
        // Trigger is the same state, so lets wait to see if the press is long enough
        if ((millis() - last_trigger_time) > MANUAL_TRIGGER_MSEC) {
            // Serial.println(millis());
            if (trigger_current) {
                if (trigger_state == false) {
                    Serial.println("Manual trigger detected");
                    trigger_mosfet();
                    // Prevent trigger happening again until it is released
                    trigger_state = true;
                } else {
                    // Serial.println("Manual trigger ignored until release state change");
                }
            } else {
                if (trigger_state == true) {
                    // Serial.println("Release trigger, state changed");
                    trigger_state = false;
                } else {
                    // Serial.println("Ignoring existing trigger release");
                }
            }
            last_trigger_time = millis();
        }
    }

}

// Ignore debug printing
#define printf_goertzel(...)
#define assert_goertzel(...)
#include "goertzel_bell103.h"

void setup() {
    Serial.begin(MAKEFILE_BAUD);
    init_goertzel();

    pinMode(SCOPE_PIN, OUTPUT);
    pinMode(ERROR_PIN, OUTPUT);
    digitalWrite(SCOPE_PIN, 0);
    digitalWrite(ERROR_PIN, 0);
    pinMode(LED_BUILTIN, OUTPUT);
    // Enable the LED initially and will turn off when the next char doesn't match the wake word
    digitalWrite(LED_BUILTIN, HIGH);

#ifdef INTERRUPT_HANDLER
    // Calculate OCR1A value for Timer1 (16-bit)
    // Timer1 is a higher resolution (16-bit) compared to Timer0
#define OCR1A_VALUE (F_CPU / SAMPLE_RATE / 8) - 1

    // Disable interrupts globally
    cli();

    // Set Timer1 to CTC mode (Clear Timer on Compare Match)
    TCCR1B |= (1 << WGM12);

    // Set prescaler to 8
    TCCR1B |= (1 << CS11);

    // Set the compare match value
    OCR1A = OCR1A_VALUE;

    // Enable Timer1 Compare Match A interrupt
    TIMSK1 |= (1 << OCIE1A);

    // Enable interrupts globally
    sei();
    Serial.println("INTERRUPT INIT");
#else
    Serial.println("LOOP INIT");
#endif // INTERRUPT_HANDLER
    Serial.println("MODEM INIT");
    Serial.print("SAMPLE_RATE=");
    Serial.println(SAMPLE_RATE);
    Serial.print("BAUD_RATE=");
    Serial.println(BAUD_RATE);
    Serial.print("SAMPLE_USEC=");
    Serial.println(SAMPLE_USEC);
    Serial.print("SAMPLES_PER_BAUD=");
    Serial.println(SAMPLES_PER_BAUD);
    Serial.print("WAKE_WORD=");
    Serial.println(wake_word);
}

void sample() {
#ifdef BENCHMARKING
    // micros() seems to have a resolution of 0 or 4 usec when tested
    unsigned long start_us = micros();
#endif // BENCHMARKING

    // Process this sample from 0-1023 and make it so it is from -512..+512
    int16_t raw_sample = analogRead(ANALOG_PIN);
    int16_t sample = raw_sample - 512;
    sample_goertzel(sample);
    goertzel_offset++;
    sample_offset++;

#undef GRAPHICAL_DEBUG
#ifdef GRAPHICAL_DEBUG
#warning Graphical debugging enabled
    // Debug out the microphone values
    // Serial.println(sample);

    // Values range from 0-1023 so graph them to fit in 64 columns
    if (raw_sample < 10) Serial.print(' ');
    if (raw_sample < 100) Serial.print(' ');
    if (raw_sample < 1000) Serial.print(' ');
    Serial.print(raw_sample);
    int16_t col = raw_sample / 16;
    for (int i = 0; i < col; i++) {
        Serial.print(" ");
    }
    Serial.println("*");
    return;
#endif // GRAPHICAL_DEBUG

    bool done_window = (goertzel_offset == SAMPLES_PER_BAUD);
    bool done_tenth = ((!reset_is_done) && (waiting_for_start) && (goertzel_offset == SAMPLES_PER_BAUD_TENTH));

    // Read more data until we have enough to calculate frequencies using Goetzel
    // This will make most samples cheap to process, and the Goetzel step more expensive
    if (!done_window && !done_tenth) {
#ifdef BENCHMARKING
        unsigned long end_us = micros();
        Serial.print("BenchSample: ");
        unsigned long diff_us = end_us - start_us;
        Serial.println(diff_us);
        if (diff_us > SAMPLE_USEC) {
            Serial.print("BenchSample larger than sample time window ");
            Serial.println(SAMPLE_USEC);
        }
#endif // BENCHMARKING
        return;
    }
#ifdef BENCHMARKING
    start_us = micros();
#endif // BENCHMARKING
    if (done_window) {
        char ch = process_goertzel();
        goertzel_offset = 0;

#ifdef BENCHMARKING
        unsigned long end_us = micros();
        Serial.print("BenchWindow: ");
        unsigned long diff_us = end_us - start_us;
        Serial.println(diff_us);
        if (diff_us > SAMPLE_USEC) {
            Serial.print("BenchWindow larger than sample time window ");
            Serial.println(SAMPLE_USEC);
        }
#else
        UNUSED(ch);
#endif // BENCHMARKING

        // Expensive char printing that doesn't affect the benchmark timing
#ifdef BENCHMARKING
        if (ch != -1) {
            Serial.print("[");
            if (isalnum(ch) || (ch == ' ')) {
                Serial.print(ch);
            } else {
                Serial.print('~');
            }
            Serial.print("]=x");
            Serial.print((unsigned char)ch, HEX);
            Serial.println();
        }
#endif // BENCHMARKING
    } else if (done_tenth) {
        bool mark_space = get_goertzel_mark_space();
        if (!mark_space) {
            // We have found the first space, indicating start of message, but do not reset_goertzel()
            // or we lose a tenth worth of energy that we've already seen, but the reset is done
            reset_is_done = 1;
        } else {
            // Did not see a space, so nuke the energy built up and try again for a fresh space detection
            reset_goertzel();
            goertzel_offset = 0;
        }

#ifdef BENCHMARKING
        unsigned long end_us = micros();
        Serial.print("BenchAlign: ");
        unsigned long diff_us = end_us - start_us;
        Serial.println(diff_us);
        if (diff_us > SAMPLE_USEC) {
            Serial.print("BenchAlign larger than sample time window ");
            Serial.println(SAMPLE_USEC);
        }
#endif // BENCHMARKING
    } else {
        Serial.println("Unexpected condition\n");
    }
}

unsigned long last_usec = 0;
uint16_t sample_count = 0;

void loop() {
// #define DEBUG_LOOP
#ifdef DEBUG_LOOP
    unsigned long last_blink = 0;
    if ((millis() - last_blink) > 1000) {
        Serial.println("DEBUG");
        Serial.println(millis());
        digitalWrite(LED_BUILTIN, !digitalRead(LED_BUILTIN));
        last_blink = millis();
    }
#endif // DEBUG_LOOP

#ifndef INTERRUPT_HANDLER
    // If there is no interrupt handler, implement the sample rate by checking the timer
    unsigned long now_usec = micros();
    unsigned long diff_usec = now_usec - last_usec;
    if (diff_usec >= SAMPLE_USEC) {
        digitalWrite(SCOPE_PIN, 1);
        sample_count++;
        sample();
        digitalWrite(SCOPE_PIN, 0);
        unsigned long used_usec = micros();
        if ((used_usec-now_usec) > SAMPLE_USEC) {
            // Toggle the oscilloscope pin to show the rate of timeouts
            digitalWrite(ERROR_PIN, !digitalRead(ERROR_PIN));
            // TODO: Every time we finish a Goertzel window, we lost a sample and we are now
            // one behind. We lose one sample per bit and each char is 10 bits. For a 3
            // char message like '123' there are 3*10=30 bits. We have drifted by 30/400=7.5%
            // but still less that one tenth of a window. We need to eventually deal with
            // this problem to prevent drift for longer messages.
#define VERBOSE_DEBUG
#ifdef VERBOSE_DEBUG
            Serial.print("sample() took too long ");
            Serial.print(used_usec-now_usec);
            Serial.print(" on loop ");
            Serial.print(sample_count);
            Serial.println();
#endif // VERBOSE_DEBUG
        }
        last_usec = now_usec;
    }
#endif // INTERRUPT_HANDLER
}

#ifdef INTERRUPT_HANDLER
ISR(TIMER1_COMPA_vect) {
    // Process one audio sample and then end quickly, do not measure time since the
    // timing functions don't advance in an interrupt handler.
    digitalWrite(SCOPE_PIN, 1);
    sample();
    digitalWrite(SCOPE_PIN, 0);
}
#endif // INTERRUPT_HANDLER

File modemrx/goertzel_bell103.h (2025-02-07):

// ---------------------------------------------------------------------
//
// HydroModem
// Underwater Bell 103 modem implementation for low-power microcontrollers
//
// Copyright (C) 2024-2025 Wayne Piekarski
// wayne@tinmith.net https://waynepiekarski.net/projects/hydro-modem.htm
//
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
// ---------------------------------------------------------------------

#ifndef vprintf_goertzel
#define vprintf_goertzel(...)
#endif

#define MARK_FREQ 1270
#define SPACE_FREQ 1070

int bit_count = 0;
unsigned char current_byte = 0;
int waiting_for_start = 1; // Flag to indicate waiting for start bit
int reset_is_done = 0;
int goertzel_offset = 0;
int sample_offset = 0;
char last_char = -1;

// 64-bit integers with 16-bit resolution passes all tests
// 16 MHz atmega328p: int64_t<<8 sample=190us, char=220us, 4KHz=250us (64-bit fixed is even slower)
//#define STYPE int64_t
//#define FIXEDRES 8 /* Any less than 8 fails */
//#define STYPEFMT "%ld"
// 16 MHz atmega328p: int32_t<<8  sample=136us, char=60us, 4KHz=250us (32-bit doesn't work)
//#define STYPE int32_t
//#define FIXEDRES 8
//#define STYPEFMT "%d"
// 16 MHz atmega328p: int16_t<<4  sample=120us, char=12us, 4KHz=250us (16-bit has almost zero char time, but can't work)
//#define STYPE int16_t
//#define FIXEDRES 2
//#define STYPEFMT "%d"
// 16 MHz atmega328p: float       sample=180us, char=116us, 4KHz=250us (sample+char is over 250us budget, but no fixed conversions)
//
// On the Lilygo esp32:esp32:lilygo_t_display_s3 ESP32-S3R8 each sample is 1-2 microseconds with floats so could run at ~400 KHz
#define STYPE float
#define FLOATRES 1
#define STYPEFMT "%18.1f"

// Implement fixed point arithmetic, use 1 (without a decimal point) for no implementation
#ifdef FLOATRES
//#warning Using floats with test multiplier
//#define FMUL(a,b) (((a)*(b))/(FLOATRES))
//#define TOFIXED(a) ((FLOATRES)*(a))
//#define FROMFIXED(a) ((a)/(FLOATRES))
#define FMUL(a,b) ((a)*(b))
#define TOFIXED(a) (a)
#define FROMFIXED(a) (a)
#else
#warning Using fixed-point arithmetic
#define FMUL(a,b) (((a)*(b))>>(FIXEDRES))
#define TOFIXED(a) ((a)*((STYPE)1<<(FIXEDRES)))
#define FROMFIXED(a) ((a)>>(FIXEDRES))
#endif


// Goertzel algorithm for frequency detection
STYPE s_mark = 0, c_mark = 0, s_space = 0, c_space = 0;
STYPE coeff_mark;
STYPE coeff_space;

#ifdef __linux__
double diff_total; // Confidence interval based on the strength of the diff values accumulated
double diff_total_log10;
#endif // __linux__

void init_goertzel (void) {
    assert_goertzel(SAMPLE_RATE > 0);
    coeff_mark = TOFIXED(2 * cos(2 * M_PI * MARK_FREQ / SAMPLE_RATE));
    coeff_space = TOFIXED(2 * cos(2 * M_PI * SPACE_FREQ / SAMPLE_RATE));
    printf_goertzel("coeff_mark=" STYPEFMT ", coeff_space=" STYPEFMT "\n", FROMFIXED(coeff_mark), FROMFIXED(coeff_space));
#ifdef __linux__
    diff_total = 0;
    diff_total_log10 = 0;
#endif // __linux__
}

void reset_goertzel (void) {
    s_mark = 0;
    c_mark = 0;
    s_space = 0;
    c_space = 0;
}

#if defined(__SIZEOF_INT128__) && defined(__linux__) && !defined(FLOATRES)
#warning Checking multiplication overflows with 128-bit integers
void check_overflow_mul(STYPE a, STYPE b) {
    STYPE r = a * b;
    __int128 aa = a;
    __int128 bb = b;
    __int128 rr = aa * bb;
    if (r != rr) {
        fprintf(stderr, "Overflow detected multiplying " STYPEFMT " by " STYPEFMT " with sizeof=%zu\n", a, b, sizeof(STYPE));
        exit(1);
    }
}
#else
inline void check_overflow_mul(STYPE, STYPE) { }
#endif

static_assert(sizeof(short) == sizeof(int16_t));
// Arduino ADC is 0-1023 while Linux is signed 16-bit integer
void sample_goertzel (int16_t sample) {
    STYPE s_prev_mark = s_mark;
    STYPE s_prev_space = s_space;

    // The sample doesn't have any official units and is an integer already, so no need to
    // use TOFIXED to round it from a float
    s_mark = /*TOFIXED*/(sample) + FMUL(coeff_mark, s_prev_mark) - c_mark;
    check_overflow_mul(coeff_mark, s_prev_mark);
    c_mark = s_prev_mark;

    s_space = /*TOFIXED*/(sample) + FMUL(coeff_space, s_prev_space) - c_space;
    check_overflow_mul(coeff_space, s_prev_space);
    c_space = s_prev_space;
}

#define UNUSED(expr) do { (void)(expr); } while (0)

// Check early what the result of mark > space is, and return a bool with the result
bool get_goertzel_mark_space (void) {
    // Calculate the power values for both frequencies, avoid the square root since we are comparing them
    STYPE power_mark  = (FMUL(s_mark, s_mark)   + FMUL(c_mark, c_mark)   - FMUL(FMUL(coeff_mark, s_mark), c_mark));
    STYPE power_space = (FMUL(s_space, s_space) + FMUL(c_space, c_space) - FMUL(FMUL(coeff_space, s_space), c_space));
    vprintf_goertzel("  PRE ");
    // vprintf_goertzel("%4d,%6d: ", goertzel_offset, sample_offset);
    vprintf_goertzel("%4.2fs ", sample_offset / (float)SAMPLE_RATE);
    vprintf_goertzel("[%c]=%d ", power_mark > power_space ? 'M' : 'S', power_mark > power_space ? 1 : 0);
    vprintf_goertzel("mark=" STYPEFMT "(%4.1f), space=" STYPEFMT "(%4.1f) -- ", FROMFIXED(power_mark), log10(FROMFIXED(power_mark)), FROMFIXED(power_space), log10(FROMFIXED(power_space)));
    if (power_mark >= power_space) {
        return true;
    } else {
        return false;
    }
}

char process_goertzel (void) {
    last_char = -1;
    // Calculate the power values for both frequencies, avoid the square root since we are comparing them
    STYPE power_mark  = (FMUL(s_mark, s_mark)   + FMUL(c_mark, c_mark)   - FMUL(FMUL(coeff_mark, s_mark), c_mark));
    STYPE power_space = (FMUL(s_space, s_space) + FMUL(c_space, c_space) - FMUL(FMUL(coeff_space, s_space), c_space));
    printf_goertzel("%4.2fs ", sample_offset / (float)SAMPLE_RATE);
    printf_goertzel("[%c]=%d ", power_mark > power_space ? 'M' : 'S', power_mark > power_space ? 1 : 0);
#ifdef __linux__
    STYPE diff = FROMFIXED(power_mark-power_space);
    char diffc = (diff < 0 ? '-' : '+');
    if (diff < 0) {
        diff = -diff;
    }
    if (FROMFIXED(diff) > 0.0001) {
        diff_total += FROMFIXED(diff);
        diff_total_log10 += log10(FROMFIXED(diff));
    }
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

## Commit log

2025-01-27 Scripts to download Arduino libraries for AVR atmega328p support with arduino-cli
2025-02-06 HydroModem implementation for Arduino atmega328p and Makefile for arduino-cli
2025-02-06 Web-browser implementation of Bell103 encoder for HydroModem
2025-02-06 Audio recorder for Arduino atmega328p with Linux client for recording and live monitoring
2025-02-06 Sample spectrogram video and thumbnail generated by Linux tests
2025-03-19 Implement CERN-OHL-S v2 license and copyright to KiCAD schematic files
2025-03-19 Implement piezo modem KiCAD schematic and PCB layout using 5V 16MHz atmega328p licensed under CERN-OHL-S v2
    [design.kicad_pcb, design.sch]
2025-03-19 Implement MOSFET-based release KiCAD schematic and PCB layout using 3.3V 8MHz atmega328p licensed under CERN-OHL-S v2
    [design.kicad_pcb, design.sch]
2025-03-20 Render a preview of the PCB layout and schematics
2025-03-25 OpenSCAD model for a nichrome release mechanism licensed under CERN-OHL-S v2
    [nichrome-release-mechanism.scad]
2025-04-17 Clean up Arduino upload and bootloader installation in Makefiles
2025-04-17 Enable LED and implement debugging in the main loop
2025-04-17 Implement LED debugging and skip printing timeout warnings in graphical debug mode
    [recordwav.ino]
2025-04-17 Scripts to play and record from the HydroModem PCB with piezo microphone
2025-04-17 Rework OpenSCAD nichrome release model to use square washers instead of nuts to fasten the wire
    [nichrome-release-mechanism.scad]
2025-04-17 Adjust AWG16 holes to 2.1mm as measured with tinned wires, AWG18 barely fit into these
    [design.kicad_pcb]
2025-04-17 Rework the piezo input to use an OPA1641 opamp
    [design.kicad_pcb, design.sch]
2025-04-17 MOSFET release implementation for Arduino atmega328p and Makefile for arduino-cli
2025-04-17 Update PNG and PDF renderings based on recent KiCAD commits
2025-04-26 Add a simplified line-in voltage version of the release-modem-atmega328p PCB
    [design.kicad_pcb, design.sch]
2025-04-26 Update README to mention new OPA1641 and line-in PCB variants
2025-04-28 Add SUP60061EL-GE3 to schematic, supports 30 amps DC instead of 10 amps from FQP47P06
    [design.sch]
2025-05-09 Download arduino CLI tools for Intel 32-bit machines
2025-05-09 Clean up comments about the pin allocations
2025-05-09 Implement wake-word detector and MOSFET release in the modemrx implementation since there was CPU time available, used with release-modem-mosfet-atmega328p-piezo PCB
2025-05-09 Implement combined modem, wake-word detector, and MOSFET release in a single atmega328p PCB
    [design.kicad_pcb, design.sch]
2025-06-07 Debian and Raspbian requires dialout to access /dev/ttyUSB* devices
2025-06-07 Fix Raspbian and non-x86-64 downloading of Arduino tools, only copy Wire patches if they are present
2025-06-07 Only enable the LED if a detected character matches the wake word, otherwise the LED is off
2025-07-23 Add Nichrome 80 32AWG text label to the OpenSCAD release mechanism
    [nichrome-release-mechanism.scad]

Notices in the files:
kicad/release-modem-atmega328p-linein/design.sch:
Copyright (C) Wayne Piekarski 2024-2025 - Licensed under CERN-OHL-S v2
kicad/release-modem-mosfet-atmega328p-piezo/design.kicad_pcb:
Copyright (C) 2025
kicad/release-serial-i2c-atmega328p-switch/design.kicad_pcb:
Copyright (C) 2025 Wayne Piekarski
